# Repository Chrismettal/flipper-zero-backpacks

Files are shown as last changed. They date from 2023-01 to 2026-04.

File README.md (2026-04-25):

# Flipper Zero Backpacks <!-- omit in toc -->





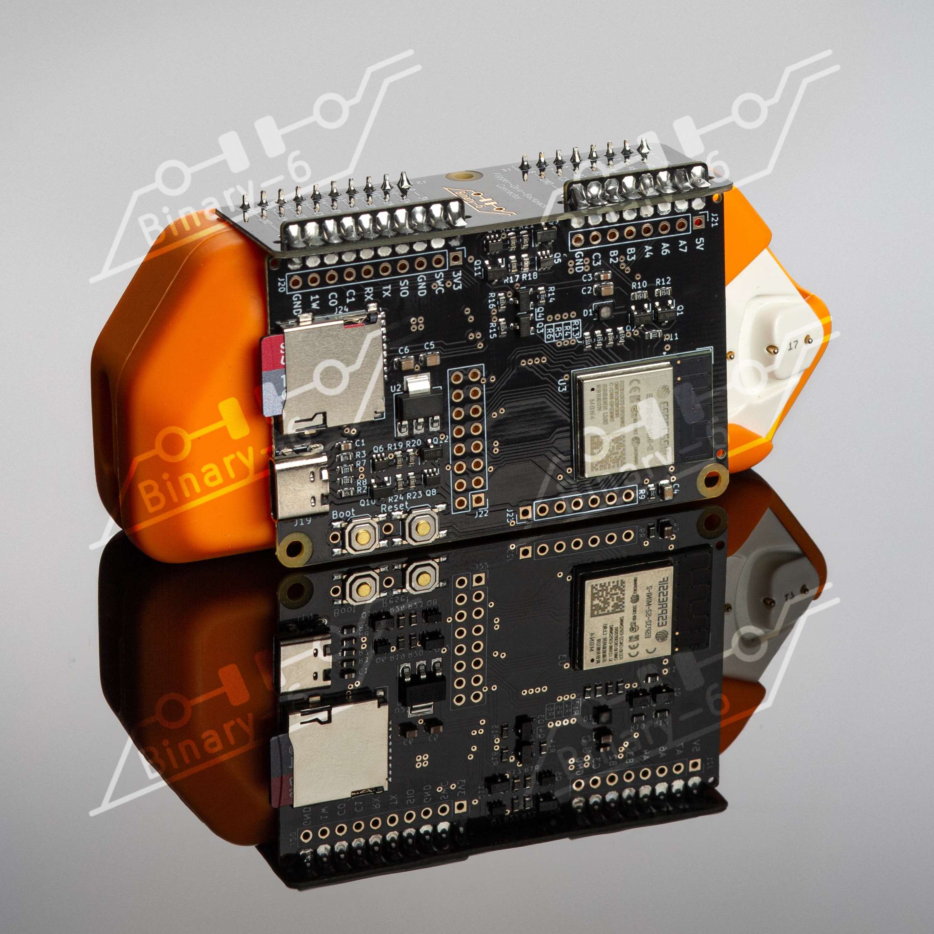
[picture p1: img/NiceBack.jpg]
NiceBack


This is a collection of addon boards for the [Flipper Zero](https://flipperzero.one/) multi-tool in the style of a backpack that clips behind the Flipper!

Right now it features only an ESP32 wifi board, like the official wifi devboard, only formatted as a backpack and with an SD card slot fitted. There is also a protoboard to create your own designs in the same formfactor.

The backpack framework is designed to fit snugly to a Flipper inside its silicone case. Without a silicone sleeve, the board will have 2mm of space around the Flipper, which might be undesireable.

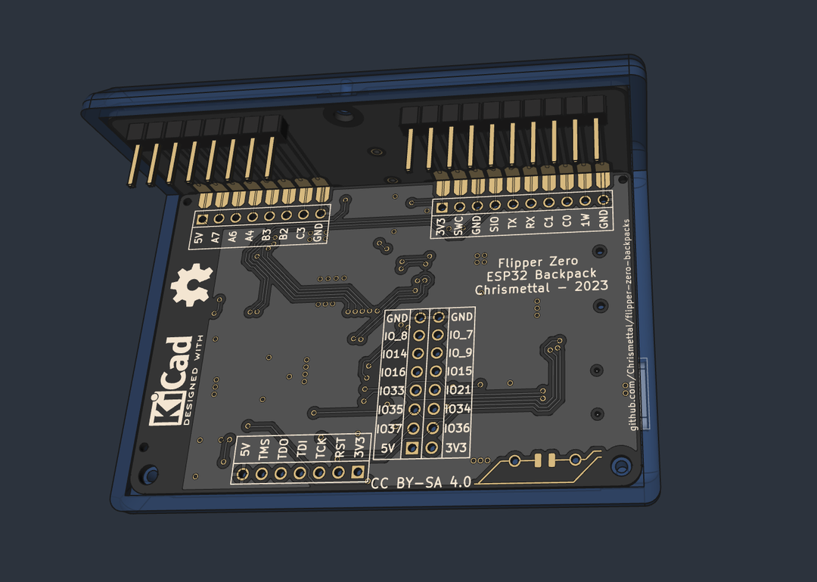
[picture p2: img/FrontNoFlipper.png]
FrontNoFlipper


Finished boards are currently stocked at [Elecrow](https://www.elecrow.com/store/Binary-6).

ElecrowBadge (https://www.elecrow.com/store/Binary-6)

**If you like my work please consider [supporting my caffeine addiction](https://github.com/Chrismettal#donations)!**

## Table of contents <!-- omit in toc -->

- [Boards](#boards)
  - [Connecting piece](#connecting-piece)
  - [ESP32 Wifi Dev board](#esp32-wifi-dev-board)
    - [Firmware](#firmware)
    - [Internal/External antenna](#internalexternal-antenna)
    - [SD Card](#sd-card)
  - [Protoboard](#protoboard)
  - [Raspberry Pi Zero W](#raspberry-pi-zero-w)
  - [Taylor Stahl - Mayhem](#taylor-stahl---mayhem)
- [Making your own](#making-your-own)
- [3D Printing](#3d-printing)
- [Building guide](#building-guide)
- [Sources](#sources)
- [Donations](#donations)
- [License](#license)

## Boards

All boards use `1mm board thickness` unless otherwise specified.

### Connecting piece

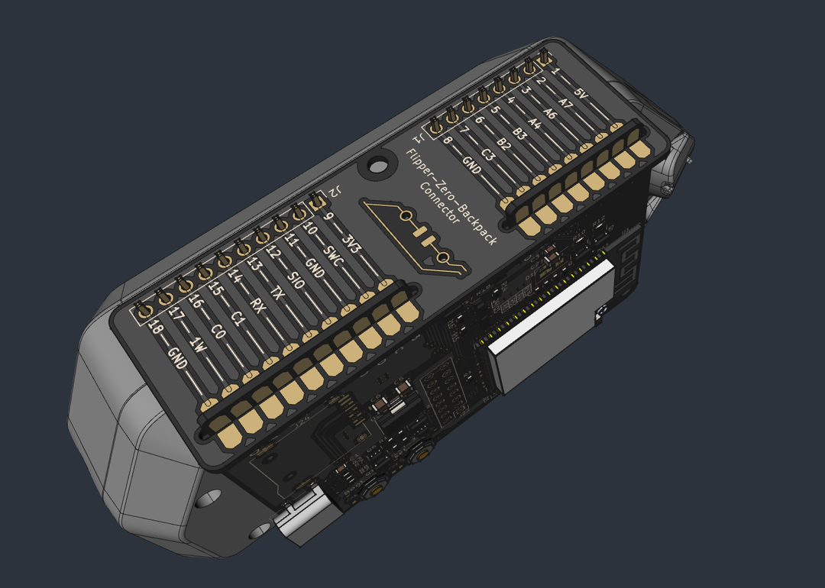
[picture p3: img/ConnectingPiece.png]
ConnectingPiece


Every board uses the same connector up top. This is what plugs into the Flipper and makes the board an actual backpack.
The addon board and the connecting piece slide into each other and get soldered at the intersection to form a solid, right angle connection.

### ESP32 Wifi Dev board

Wifi

[**Buy on Elecrow**](https://www.elecrow.com/flipper-zero-wifi-backpack-esp32-s2-mini-new-ic.html)

Very similar to the [official Wifi dev board](https://shop.flipperzero.one/collections/flipper-zero-accessories/products/wifi-devboard). Additionally includes a micro SD card slot so you don't have to mod the official board yourself. 

The board has been modified to accomodate the `ESP32-S2-MINI-2` version of the ESP32 modules, as the original `WROVER` variant has become unavailable. Internally the IC is mostly identical.

Other than that all guides applicable to the official Wifi dev board are also applicable here.

In this repo, there are 3D files for boards with the internal, as well as the external antenna available. The board is the same between the two, only the part number of the ESP changes.

#### Firmware

The board ships with the [Black Magic debugger firmware](https://black-magic.org/), just like the official board. Alternatively you can use an alternate firmware like the [ESP32 Marauder](https://github.com/justcallmekoko/ESP32Marauder/wiki/flipper-zero) by [JustCallMeKoko](https://github.com/justcallmekoko) if you want to get spicy.

**Every firmware that works on the [official dev board](https://shop.flipperzero.one/collections/flipper-zero-accessories/products/wifi-devboard) should also work on this backpack**

#### Internal/External antenna

Previous versions of this board used the `WROVER` variant of the ESP32, which offered internal and external antenna options on the same module by flipping a jumper. As this chip has become unavailable, the board has been redesigned for the `ESP32-S2-MINI-2`, which at first is internal-antenna-only. To use an external antenna, the `ESP32-S2-MINI-2` would need to be mounted. 

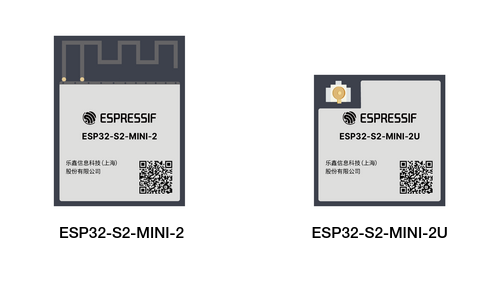
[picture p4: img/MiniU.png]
ESP32 MINI vs MINI U


#### SD Card

The ESP seems to be pretty restrictive in SD Card compatibility especially when running Marauder. This is not a limitation of this specific design but inherent to the ESP32. I've had luck with older and smaller SD cards sub 16 GB and Class 10 at max. OLDER `Sandisk Ultra Micro SDHC I` seem to work pretty well when formatted to `FAT32`.

### Protoboard

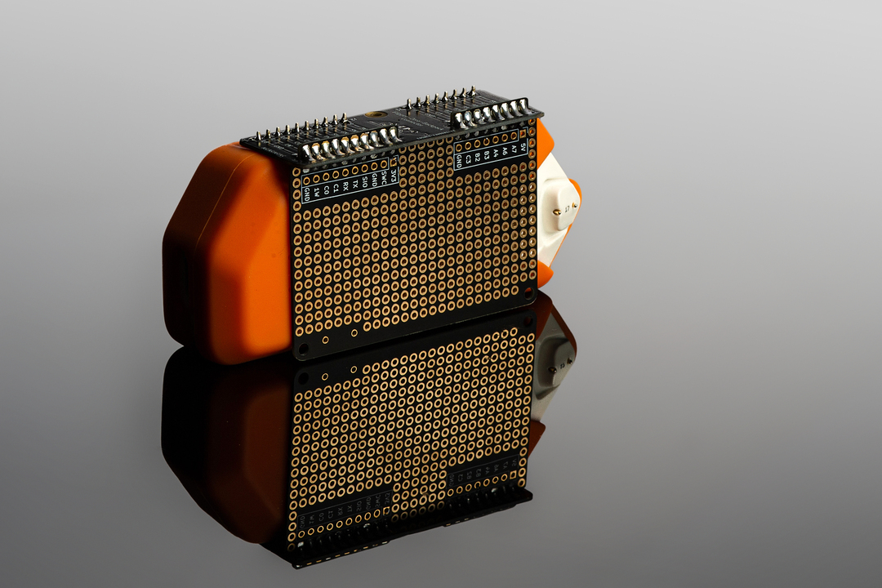
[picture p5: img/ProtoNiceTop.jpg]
Protoboard


A simple `2.54mm` pitch protoboard backpack, fitting the same case as the ESP32 board. While it is through hole, beware that there isn't much space between the Flippers silicone case and the board, so make sure to only put taller components on the side facing away from the flipper, and stay pretty flat when wiring on the bottom side. Also remember that the bottom side will be somewhat exposed, so you should consider placing and wiring mostly on the encased side.

### Raspberry Pi Zero W

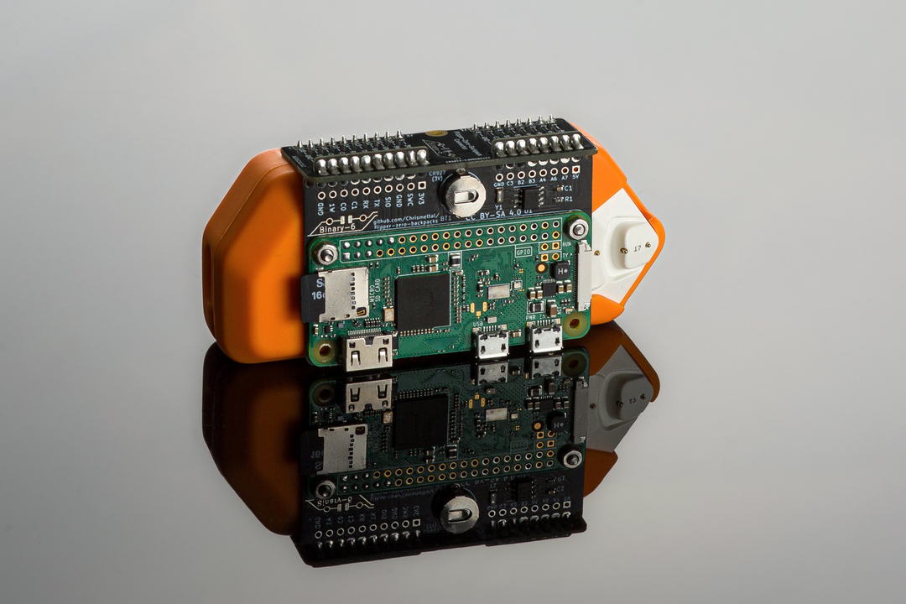
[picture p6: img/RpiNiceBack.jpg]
Raspberry


This is an adapter to supply and connect a Raspberry Pi Zero W to the Flipper via UART.

The board was mainly created for the [Flippagotchi](https://github.com/Matt-London/pwnagotchi-flipper) app, which renders a [Pwnagotchi](https://pwnagotchi.ai/)`s screen onto the flipper.

Additionally, the board includes a `PCF8523` realtime clock so your Pwnagotchi actually knows what time it is. The battery used for the RTC is a `CR927`.

To set up the Realtime clock, you can follow the guide on the [Pwnagotchi docs](https://pwnagotchi.ai/configuration/#connecting-to-pi0w-with-microusb-cable-on-linux-host) as well as [Adafruit](https://learn.adafruit.com/adding-a-real-time-clock-to-raspberry-pi/set-rtc-time).

If you don't want to connect your pwnagotchi to the internet, you can always set its time with `'sudo date -s 'YYYY-MM-DD HH:MM:SS'` , before writing the Raspberry's time the RTC with `sudo hwclock -w`

### Taylor Stahl - Mayhem

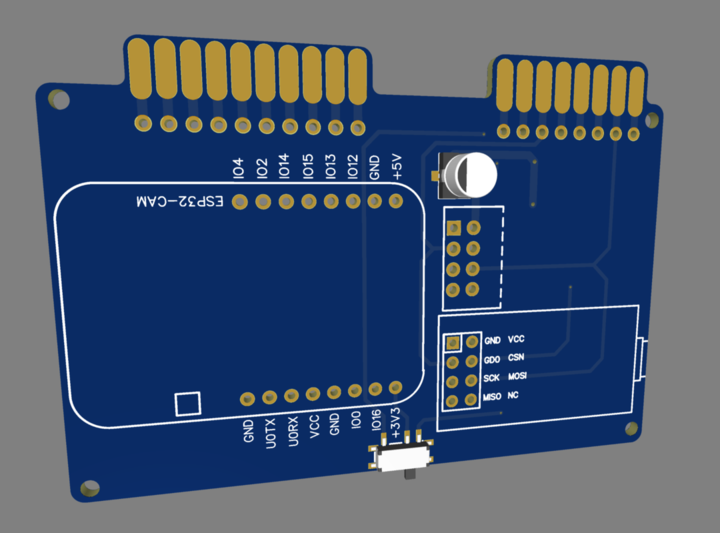
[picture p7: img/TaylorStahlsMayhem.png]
Mayhem


This is a [Flipper Zero Mayhem](https://github.com/eried/flipperzero-mayhem) backpack created by [Taylor Stahls](taylor.stahls@gmail.com) done with EasyEDA.

It uses the same backpack connector as the other boards found here to implement an ESP32-CAM, CC1101 and NRF24 in a backpack format. A switch was added to choose between the CC1101 and the NRF24 being active.

I personally haven't yet played around with this board, as Taylor merely asked me to add his board to this repo to respect the original license. Taylor is currently setting up his own Tindie shop to sell his Mayhem boards eventually. Link to be added once public.

## Making your own

All files to order your own boards from existing designs can be found under `/pcb/<BoardName>/FabricationFiles`. This includes Gerbers as well as BOMs for PCBA so the boards arrive fully built. All files were exported to be ordered at JLCPCB and use LCSC part numbers.

**All boards need to be ordered as 1mm thickness so they fit together well!**

There is also a clean KiCad project under `/pcb/Clean/` to create original designs. If you end up creating your own design I would love to merge your fork into this repo!

## 3D Printing

A 3D printable case project is included in `/3d_printing/flipper-zero-backpacks.FCStd`.

You can use [FreeCAD](https://www.freecad.org/) to open and modify it. 

A `bare` version, as well as one fitting the `ESP32` board have been exported as `.step` and `.3mf` files into `/3d_printing/`.

The cases can be printed without any supports and are best printed in PETG, but there is no reason why PLA wouldn't be sufficient.

## Building guide

Please head over to [the building guide document](/Guide/README.md)!

## Sources

- [ESP32-S2-WROVER step file](https://grabcad.com/library/esp32-s2-wrover-1)

## Donations

**If you like my work please consider [supporting my caffeine addiction](https://github.com/Chrismettal#donations)!**

## License

 <br />This work is licensed under a <a rel="license" href="http://creativecommons.org/licenses/by-sa/4.0/">Creative Commons Attribution-ShareAlike 4.0 International License</a>.

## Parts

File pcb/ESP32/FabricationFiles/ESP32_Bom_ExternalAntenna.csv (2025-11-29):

Comment | Designator | Footprint | LCSC
100nF | C1,C3 | Capacitor_SMD:C_0603_1608Metric | C14663
22uF | C2,C6 | Capacitor_SMD:C_0805_2012Metric | C45783
10uF | C4,C5 | Capacitor_SMD:C_0805_2012Metric | C15850
LED_RBAG | D1 | MeineBib:LED_RGB_2.1mm_Foshan_Nationstar | C2874116
XUNPU TYPEC-304-ACP16 | J19 | MeineBib:USB_C_Receptacle_XUNPU_TYPEC-304-ACP16 | C2982555
Micro_SD_XUNPU__TF-115 | J24 | MeineBib:Micro_SD_XUNPU_TF-115 | C266620
AO3400A | Q1,Q2 | Package_TO_SOT_SMD:SOT-23 | C20917
AO3401A | Q3,Q4,Q9,Q10,Q11,Q12 | Package_TO_SOT_SMD:SOT-23 | C15127
MMDT2907A-7-F | Q5,Q6,Q7,Q8 | Package_TO_SOT_SMD:SOT-363_SC-70-6 | C460232
4K7 | R15,R16 | Resistor_SMD:R_0603_1608Metric | C23162
100k | R17,R18,R19,R20,R21,R22,R23,R24 | Resistor_SMD:R_0603_1608Metric | C25803
5.1K | R2,R3 | Resistor_SMD:R_0603_1608Metric | C23186
100R | R4 | Resistor_SMD:R_0603_1608Metric | C22775
150R | R5,R10,R12,R13 | Resistor_SMD:R_0603_1608Metric | C22808
510R | R6 | Resistor_SMD:R_0603_1608Metric | C23193
22R | R7,R8 | Resistor_SMD:R_0603_1608Metric | C23345
10k | R9,R11,R14 | Resistor_SMD:R_0603_1608Metric | C25804
Reset | SW1 | Button_Switch_SMD:SW_SPST_TL3342 | C318884
Boot | SW2 | Button_Switch_SMD:SW_SPST_TL3342 | C318884
ESP32-S2-MINI-2U | U3 | RF_Module:ESP32-S2-MINI-2U | C3013907
AMS1117-3.3 | U2 | Package_TO_SOT_SMD:SOT-223-3_TabPin2 | C6186

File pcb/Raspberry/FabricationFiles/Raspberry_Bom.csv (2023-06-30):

Comment | Designator | Footprint | LCSC
CR927 (3V) | BT1 | MeineBib:MY-927-01 CR927 Battery Holder | C964850
2.2µF | C1 | Capacitor_SMD:C_0603_1608Metric | C23630
1K | R1 | Resistor_SMD:R_0603_1608Metric | C21190
PCF8523T | U1 | Package_SO:SOIC-8_3.9x4.9mm_P1.27mm | C2651516
32.768kHz | Y1 | Crystal:Crystal_SMD_3215-2Pin_3.2x1.5mm | C32346

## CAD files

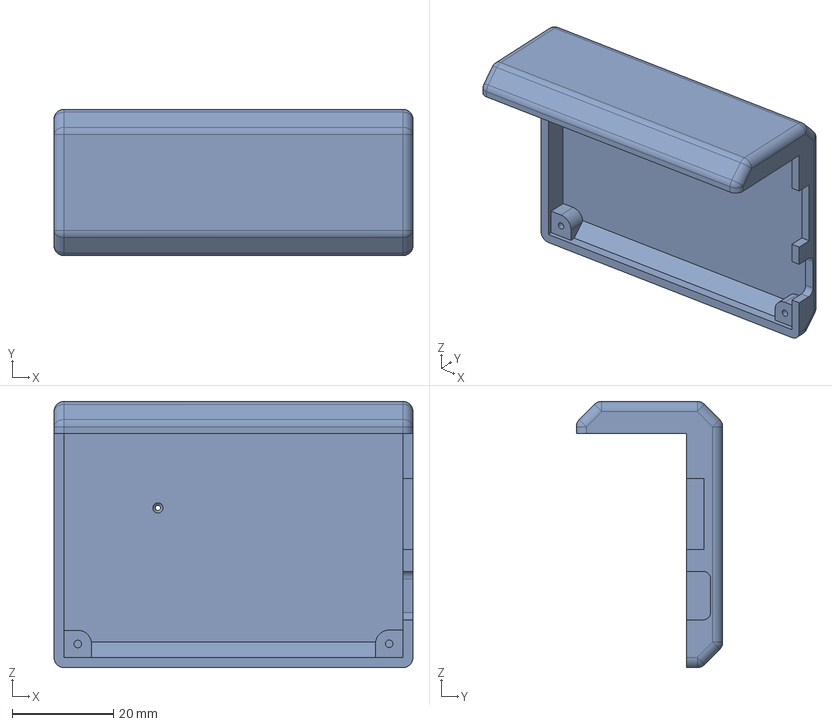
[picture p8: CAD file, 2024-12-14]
3d_printing/ESP32_InternalAntenna.step
70.8 x 28.9 x 52.5 mm

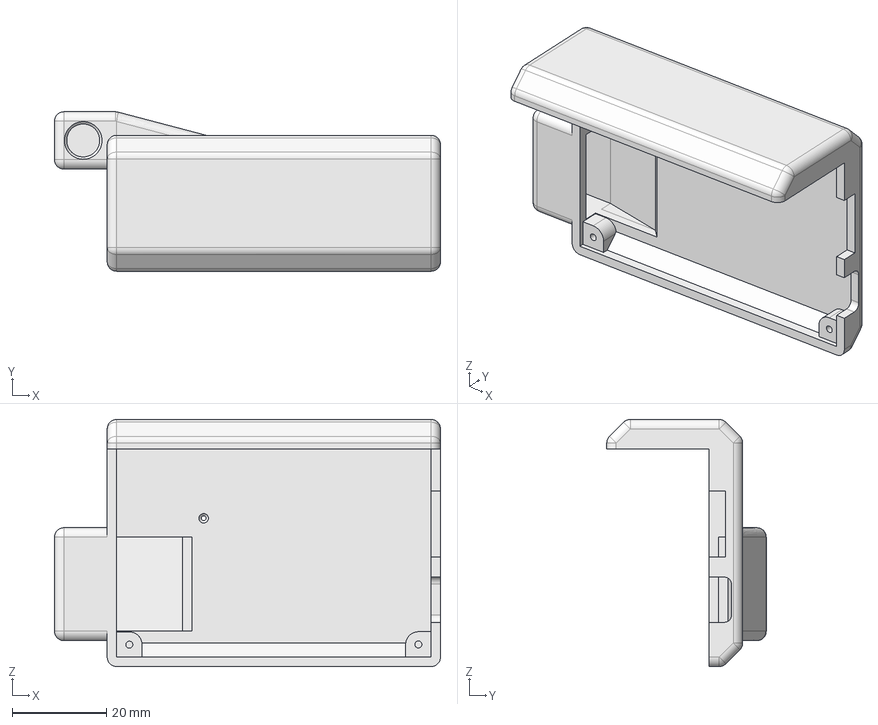
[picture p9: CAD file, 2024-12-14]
3d_printing/ESP32_ExternalAntenna.step
82.0 x 33.9 x 52.5 mm

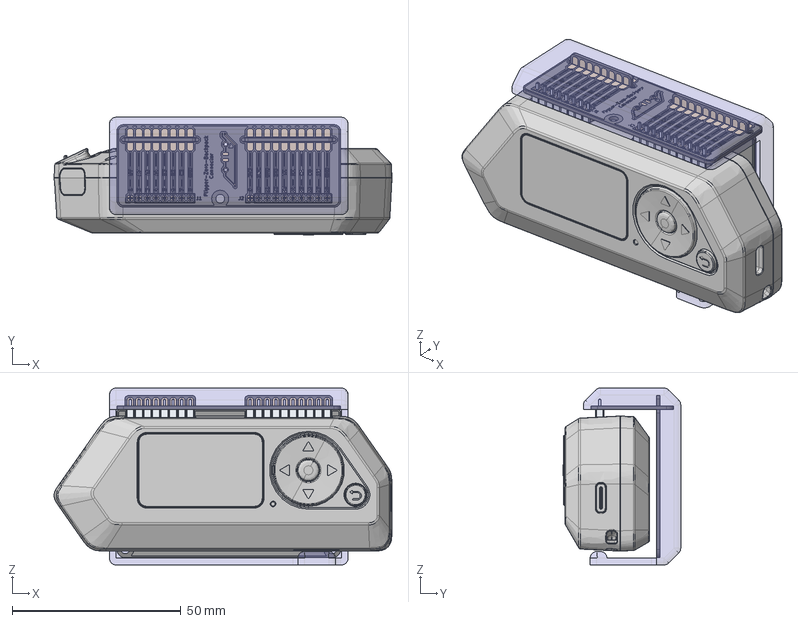
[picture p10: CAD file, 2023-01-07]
3d_printing/flipper-zero-backpacks.FCStd
100.3 x 34.9 x 52.5 mm
flipper-zero-body-3d
J2_PinHeader_1x10_P254mm_Vertical_2ab44282e7fd
J1_PinHeader_1x08_P254mm_Vertical_c51476792754
Pcb_2d78
topPads_2d78
topTracks_2d78
topZones_2d78
botPads_2d78
botTracks_2d78
botZones_2d78
topSilks_7e
Pcb_c4c1
topPads_c4c1
topZones_c4c1
botPads_c4c1
botZones_c4c1
Case

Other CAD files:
3d_printing/Bare.step
3d_printing/Raspberry.step
3d_printing/Bare.3mf
3d_printing/ESP32_ExternalAntenna.3mf
3d_printing/ESP32_InternalAntenna.3mf
3d_printing/Raspberry.3mf

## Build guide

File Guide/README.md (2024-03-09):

# Building guide <!-- omit in toc -->

- [BOM](#bom)
    - [Bare / Prototype](#bare--prototype)
    - [ESP32 Internal Antenna](#esp32-internal-antenna)
    - [ESP32 External Antenna](#esp32-external-antenna)
    - [Raspberry Pi](#raspberry-pi)
- [3D printing](#3d-printing)
- [Assembling the boards](#assembling-the-boards)
- [Raspberry Pi specific subassembly](#raspberry-pi-specific-subassembly)
- [Firmware flash](#firmware-flash)
    - [ESP32](#esp32)

## BOM

These BOMs are for assembling a finished backpack and are to be seen additional to the PCBA BOMs in the respective pcb folder. These BOMs will not include any parts that are placed on the board by the PCB fabhouse.

This list is also what you would get, if you were to buy a kit through [Tindie](https://www.tindie.com/stores/binary-6/).

### Bare / Prototype

| Name | Part number  | Amount | Link |
| :--- | :--- | :----- | :--- |
| Protoboard PCB | N/A | 1 | [PCB](/pcb/Protoboard/FabricationFiles/Protoboard_Gerb.zip) |
| Connecting-piece PCB | N/A | 1 | [PCB](/pcb/Connecting-piece/FabricationOutputs/Connecting-piece_Gerb.zip) |
| 8 x 2.54mm pin header | N/A | 1 | N/A |
| 10 x 2.54mm pin header | N/A | 1 | N/A |
| 3D printed case | N/A | 1 | [Case](/3d_printing/Bare.3mf) |
| M2 x 5mm self tapping screw | GB2670.2 5mm | 3 | [M2 x 5 noname screws](https://de.aliexpress.com/item/1005004325435136.html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) |

### ESP32 Internal Antenna

| Name | Part number  | Amount | Link |
| :--- | :--- | :----- | :--- |
| ESP32 PCB (With `ESP32-S2-WROVER`, `C701333`) | N/A | 1 | [PCB](/pcb/ESP32/FabricationFiles/ESP32_Gerb.zip), [PCBA BOM](/pcb/ESP32/FabricationFiles/ESP32_Bom_InternalAntenna.csv) |
| Connecting-piece PCB | N/A | 1 | [PCB](/pcb/Connecting-piece/FabricationOutputs/Connecting-piece_Gerb.zip) |
| 8 x 2.54mm pin header | N/A | 1 | N/A |
| 10 x 2.54mm pin header | N/A | 1 | N/A |
| 3D printed case | N/A | 1 | [Case](/3d_printing/ESP32_InternalAntenna.3mf) |
| M2 x 5mm self tapping screw | GB2670.2 5mm | 3 | [M2 x 5 noname screws](https://de.aliexpress.com/item/1005004325435136.html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) |

### ESP32 External Antenna

| Name | Part number  | Amount | Link |
| :--- | :--- | :----- | :--- |
| ESP32 PCB (With `ESP32-S2-WROVER-I`, `C701334`) | N/A | 1 | [PCB](/pcb/ESP32/FabricationFiles/ESP32_Gerb.zip), [PCBA BOM](/pcb/ESP32/FabricationFiles/ESP32_Bom_InternalAntenna.csv) |
| Connecting-piece PCB | N/A | 1 | [PCB](/pcb/Connecting-piece/FabricationOutputs/Connecting-piece_Gerb.zip) |
| 8 x 2.54mm pin header | N/A | 1 | N/A |
| 10 x 2.54mm pin header | N/A | 1 | N/A |
| 3D printed case | N/A | 1 | [Case](/3d_printing/ESP32_InternalAntenna.3mf) |
| M2 x 5mm self tapping screw | GB2670.2 5mm | 3 | [M2 x 5 noname screws](https://de.aliexpress.com/item/1005004325435136.html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) |
| 2.4GHz Wifi Antenna with IPX to RP-SMA cable | N/A | 1 | [Noname Antenna](https://de.aliexpress.com/item/1005003489327360.html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) |

### Raspberry Pi

| Name | Part number | Amount | Link |
| :--- | :--- | :----- | :--- |
| Raspberry PCB | N/A | 1 | [PCB](/pcb/Raspberry/FabricationFiles/Raspberry_Gerb.zip), [PCBA BOM](/pcb/Raspberry/FabricationFiles/Raspberry_Bom.csv) |
| Connecting-piece PCB | N/A | 1 | [PCB](/pcb/Connecting-piece/FabricationOutputs/Connecting-piece_Gerb.zip) |
| 8 x 2.54mm pin header | N/A | 1 | N/A |
| 10 x 2.54mm pin header | N/A | 1 | N/A |
| Raspberry Pi Zero W | RPD08818W | 1 | [Elecrow Rpi Zero W](https://www.elecrow.com/raspberry-pi-zero-w.html) |
| 3D printed case | N/A | 1 | [Case](/3d_printing/ESP32_InternalAntenna.3mf) |
| M2 x 5mm self tapping screw | GB2670.2 5mm | 3 | [M2 x 5 noname screws](https://de.aliexpress.com/item/1005004325435136.html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) |
| M2.5 Hexagon Nut | DIN-EN-ISO 4032 | 2 | [Norm](https://www.fasteners.eu/standards/ISO/4032/) |
| M2.5 x 6mm countersunk machine screw | ISO 14581 | 2 | [Norm](https://www.fasteners.eu/standards/ISO/14581/) |
| CR927 (3V) Battery | N/A | 1 | N/A |

## 3D printing

In the [3d_printing](/3d_printing/) folder you'll find a case option for every design variant. The cases are to be printed with PETG with 0.15mm layer height and a 0.4mm nozzle. Larger layer heights or nozzles might make the boards not fit easily.

The cases currently provided are:

- Bare (Case without cutouts for prototyping)
- ESP32_InternalAntenna (Wifi dev board using the on-board ESP32 antenna. Sleek and compact)
- ESP32_ExternalAntenna (Wifi dev board using an external antenna. Powerful but bulky)
- Raspberry (Pi Zero mount)

## Assembling the boards

**Step 1 - Clamp the back board vertically**

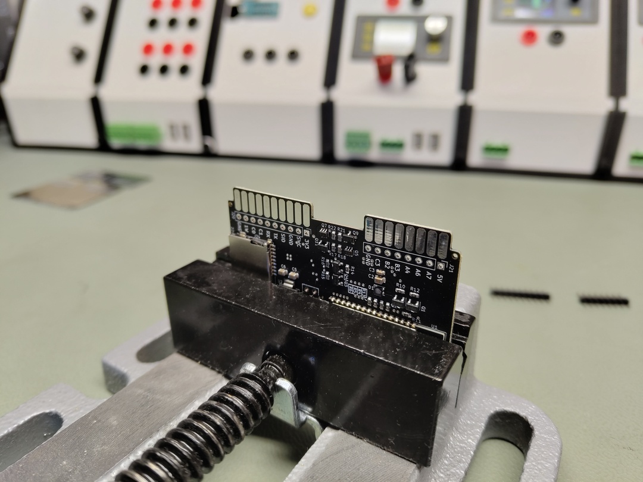
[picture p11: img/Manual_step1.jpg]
Step1


**Step 2 - Slide on the connecting piece**

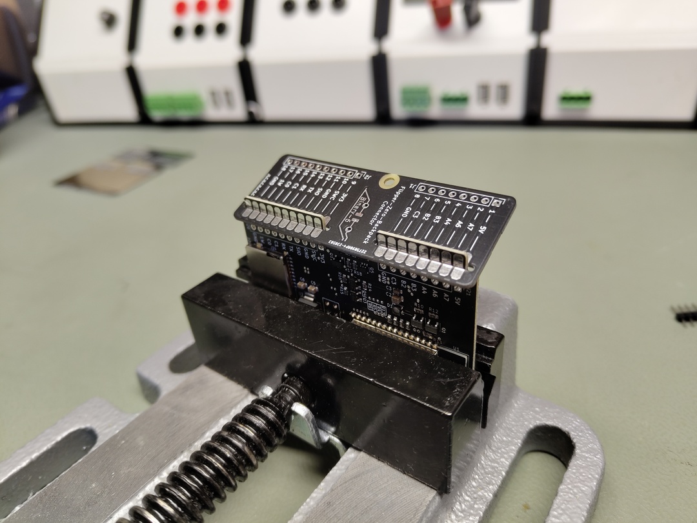
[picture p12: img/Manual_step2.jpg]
Step2


**Step 3 - Solder down one of the connectors**

You don't have to care about the angle of the boards for now.

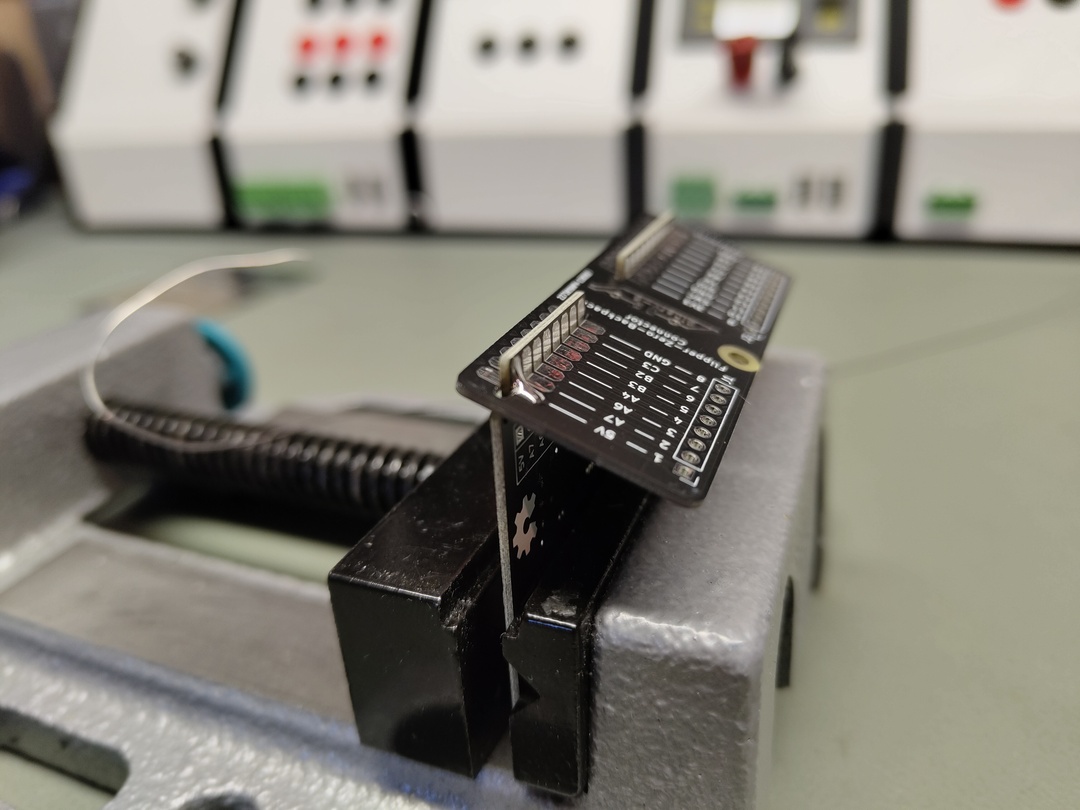
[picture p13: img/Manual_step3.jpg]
Step3


**Step 4 - Reflow the connection, aligning the boards at 90 degrees**

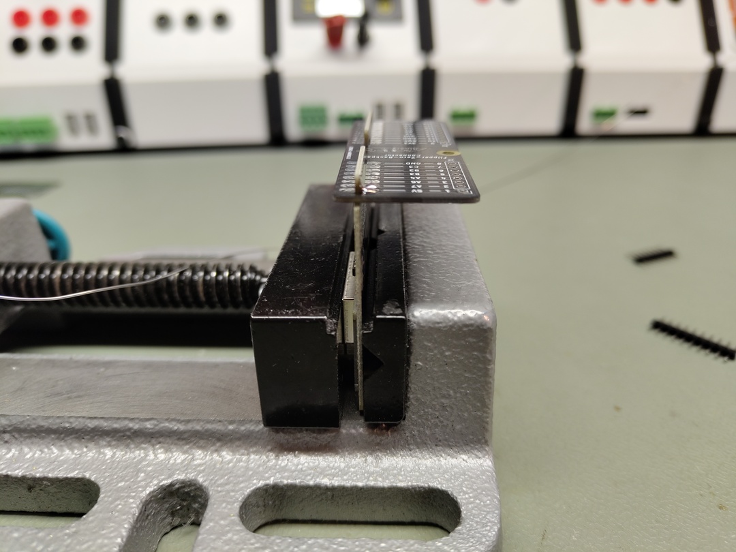
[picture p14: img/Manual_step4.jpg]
Step


**Step 5 - Make sure the boards are also aligned when viewed from the front**

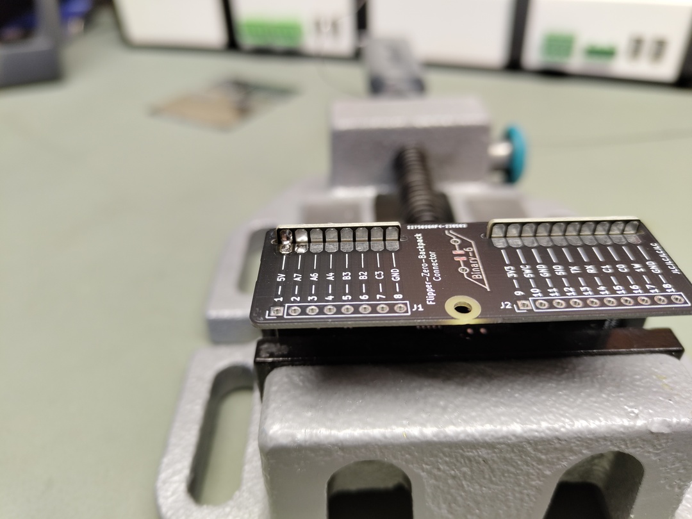
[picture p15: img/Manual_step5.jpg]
Step5


**Step 6 - Solder the remaining connections on the top**

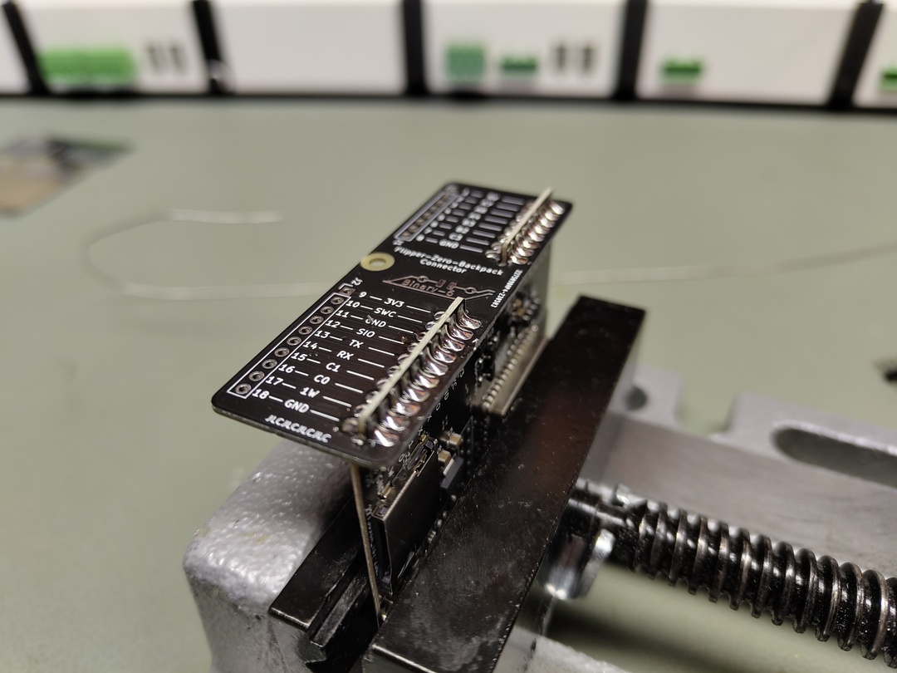
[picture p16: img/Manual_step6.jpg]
Step6


**Step 7 - Make sure that none of the connections are bridged between the pads horizontally**

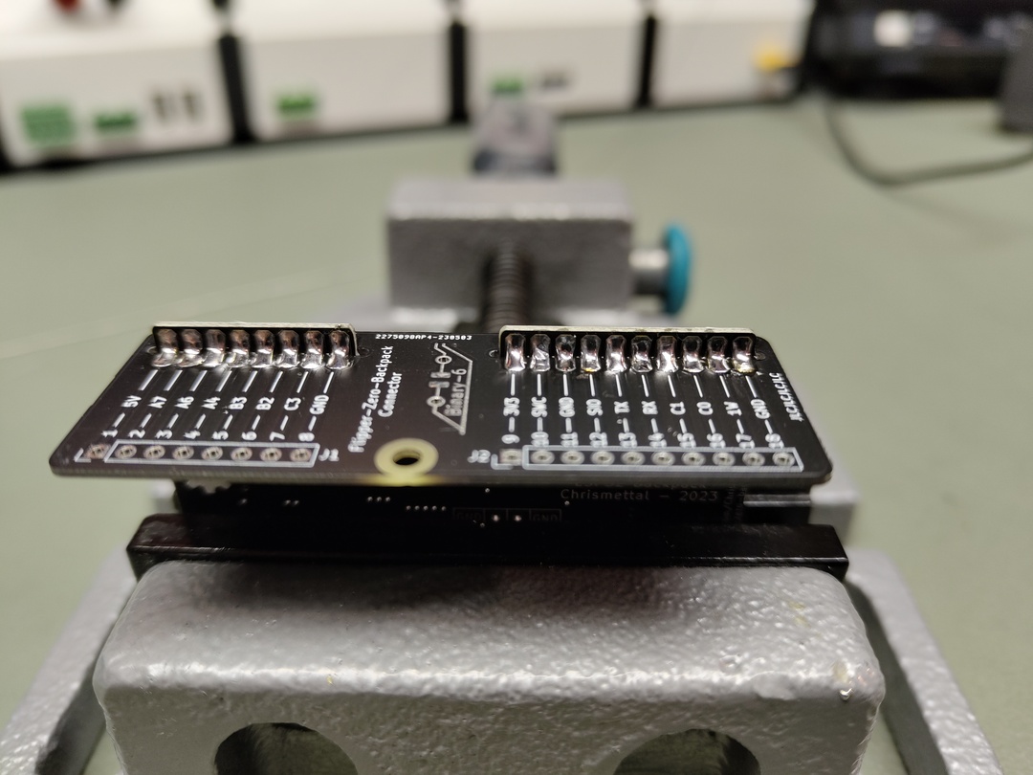
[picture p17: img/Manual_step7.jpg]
Step7


**Step 8 - Flip the board around so you can see the bottom connections**

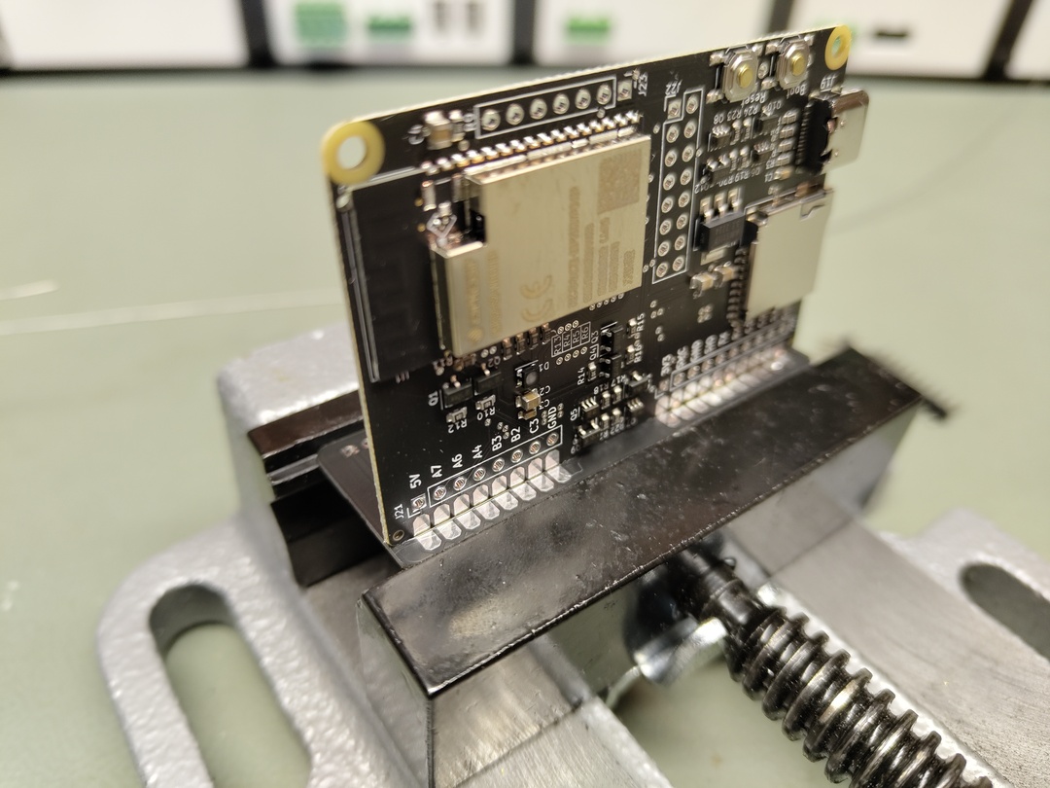
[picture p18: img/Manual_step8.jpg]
Step8


**Step 9 - Solder the bottom connections**

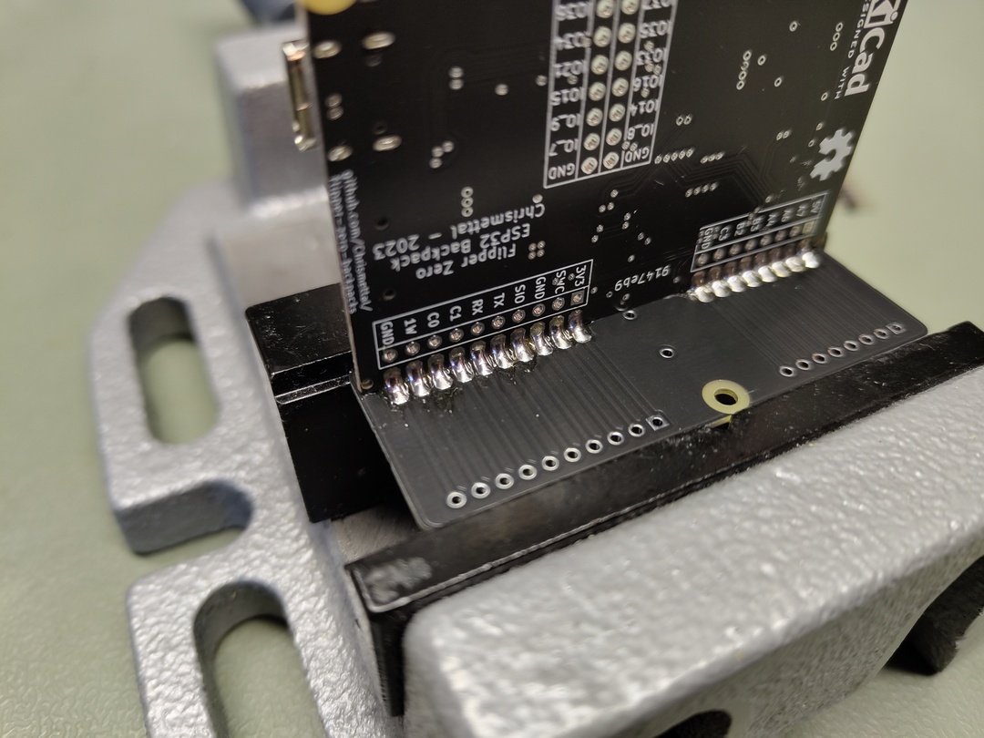
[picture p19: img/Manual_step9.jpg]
Step9


**Step 10 - Flip the board around again and solder the pin headers**

Make sure to get them at a right angle to the board as well. Otherwise you will put stress on the board when inserting into the Flipper.

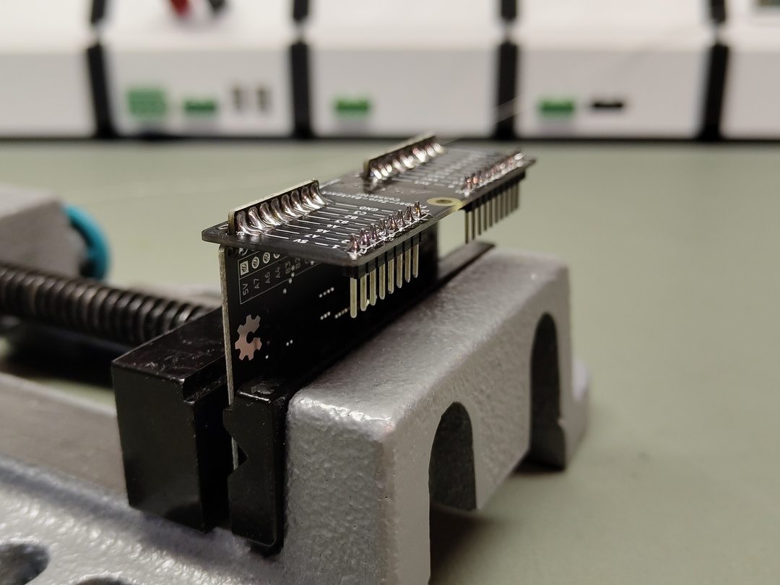
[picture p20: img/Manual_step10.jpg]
Step10


**Step 11 - Optional - Find the 3D printed case and screws**

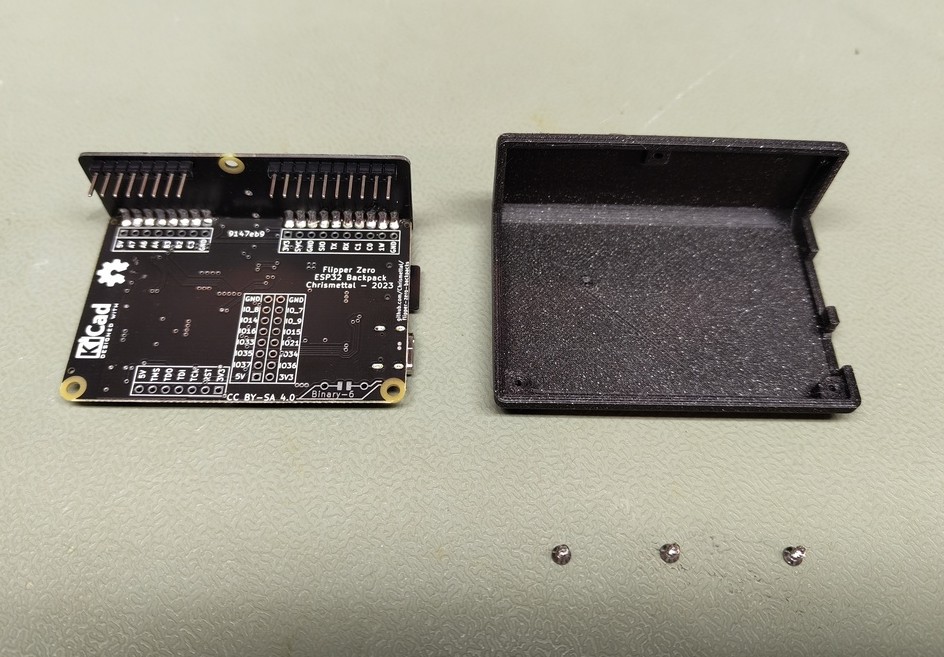
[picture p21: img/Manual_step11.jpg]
Step11


<details>
<summary markdown="span">Excursion: Installing the antenna jack for external antenna boards</summary>

**Step 11.1 - Insert the antenna jack into the slot and fix nut from the outside**

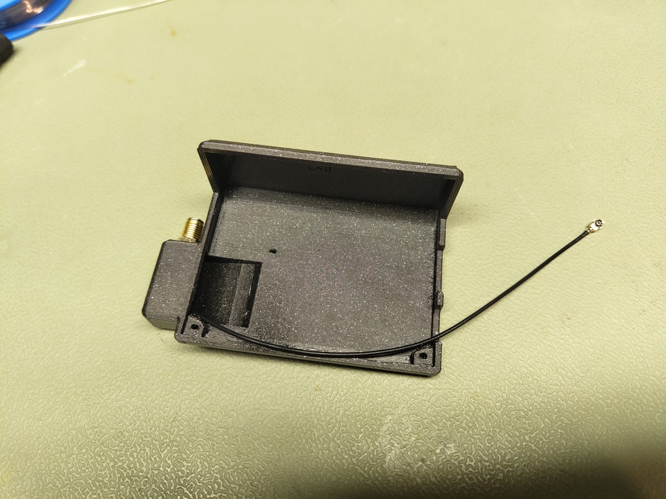
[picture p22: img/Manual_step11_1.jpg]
Step11.1


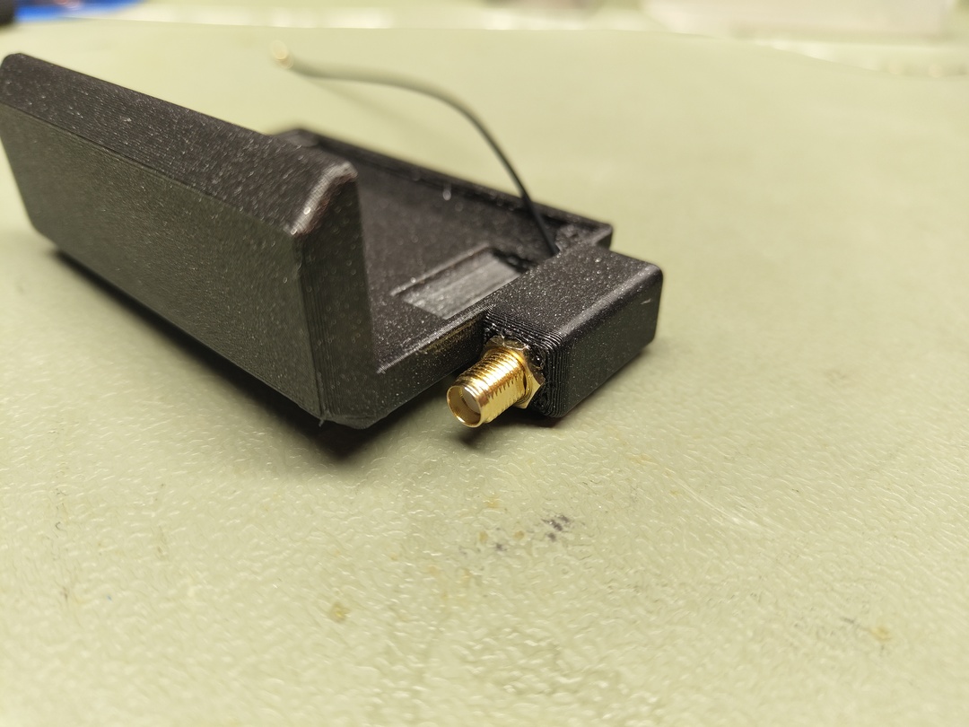
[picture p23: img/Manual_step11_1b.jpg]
Step11.1b


**Step 11.2 - Plug antenna extension into the board**

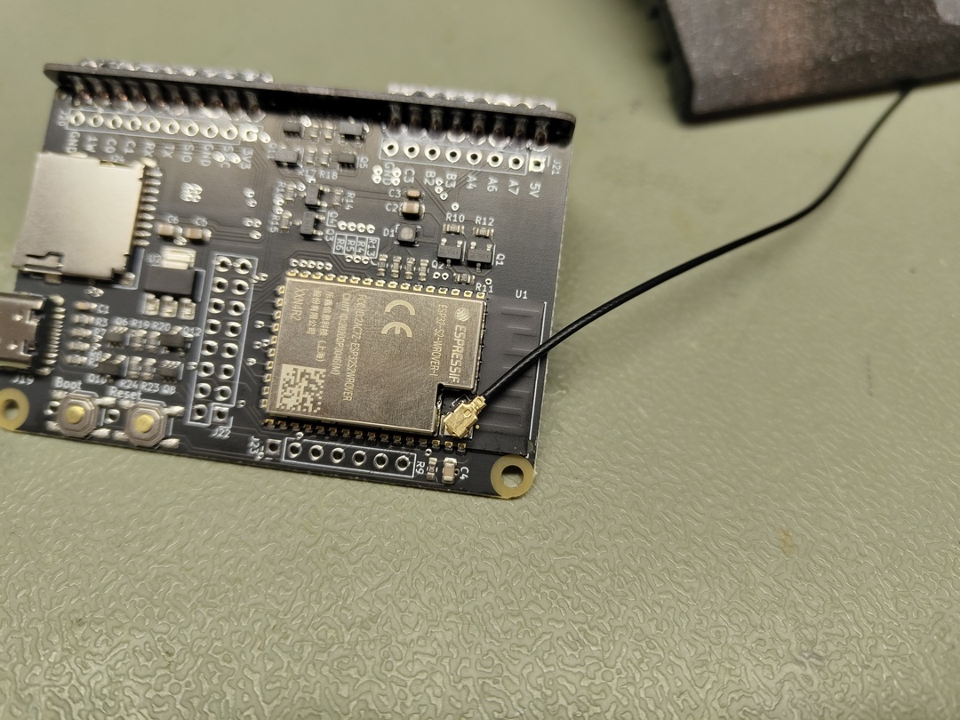
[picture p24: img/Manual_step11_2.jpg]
Step11.2


**Step 11.3 - Carefully route the extension while inserting the board**

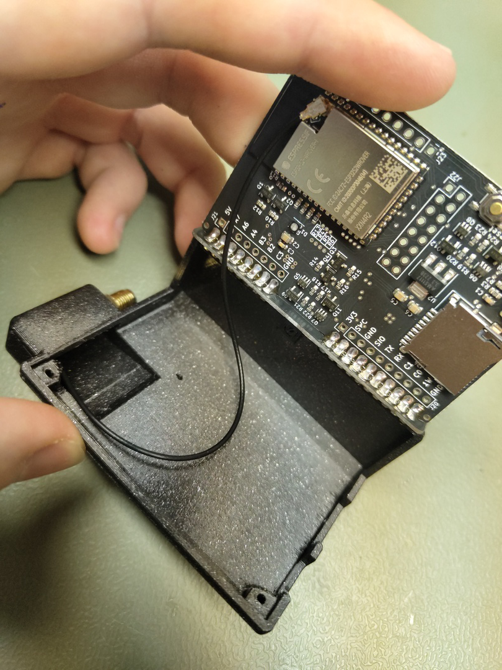
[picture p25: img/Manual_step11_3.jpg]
Step11.3


**Step 11.4 - Make sure the board is seated without pinching the wire**

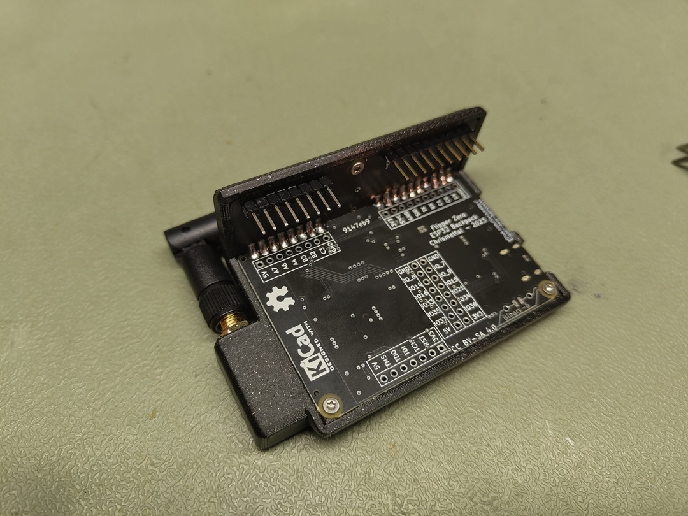
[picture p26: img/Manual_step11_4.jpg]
Step11.4


</details>

**Step 12 - Slide the board into the case and screw down the 3 mounting points**

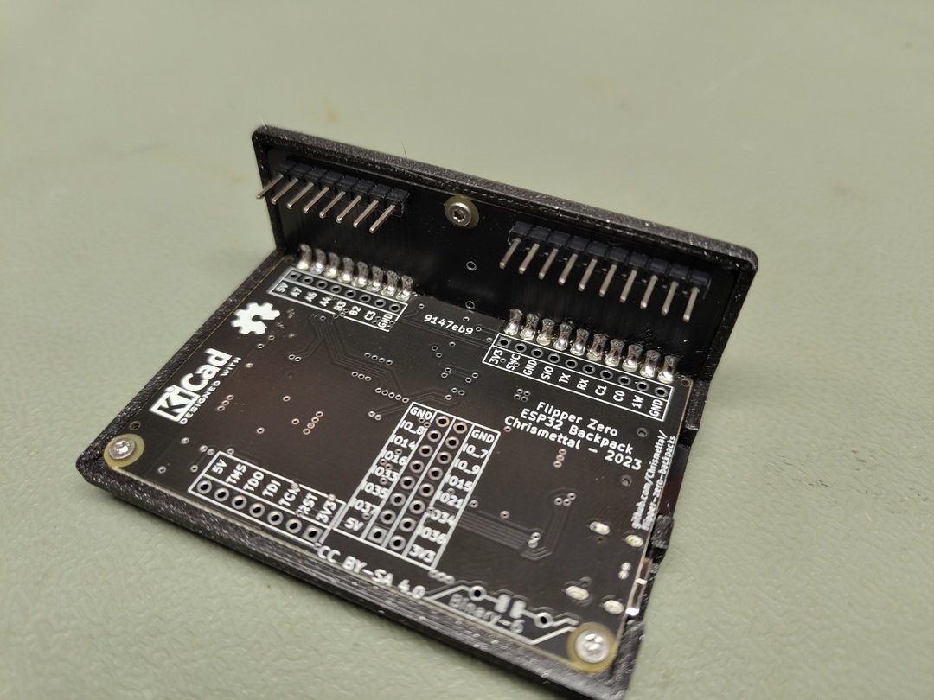
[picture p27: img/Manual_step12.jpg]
Step12


## Raspberry Pi specific subassembly

**Step 0 - Find the Raspberry board and read the instructions as printed on the board**

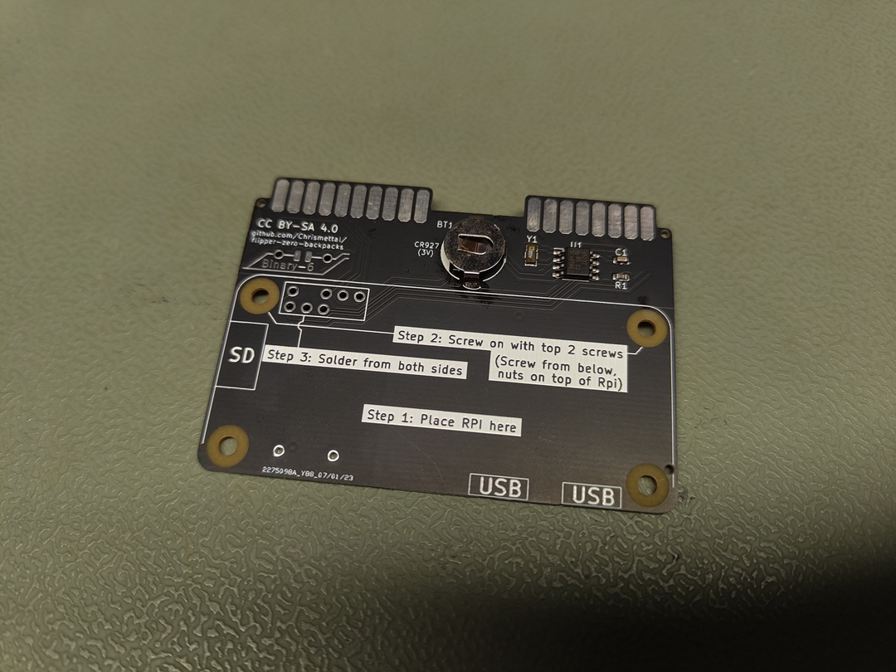
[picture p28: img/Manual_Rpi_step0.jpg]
Step0


**Step 1 - Place the Raspberry Pi Zero W on top of the board**

Note the lack of pin headers. The board won't fit with headers installed!

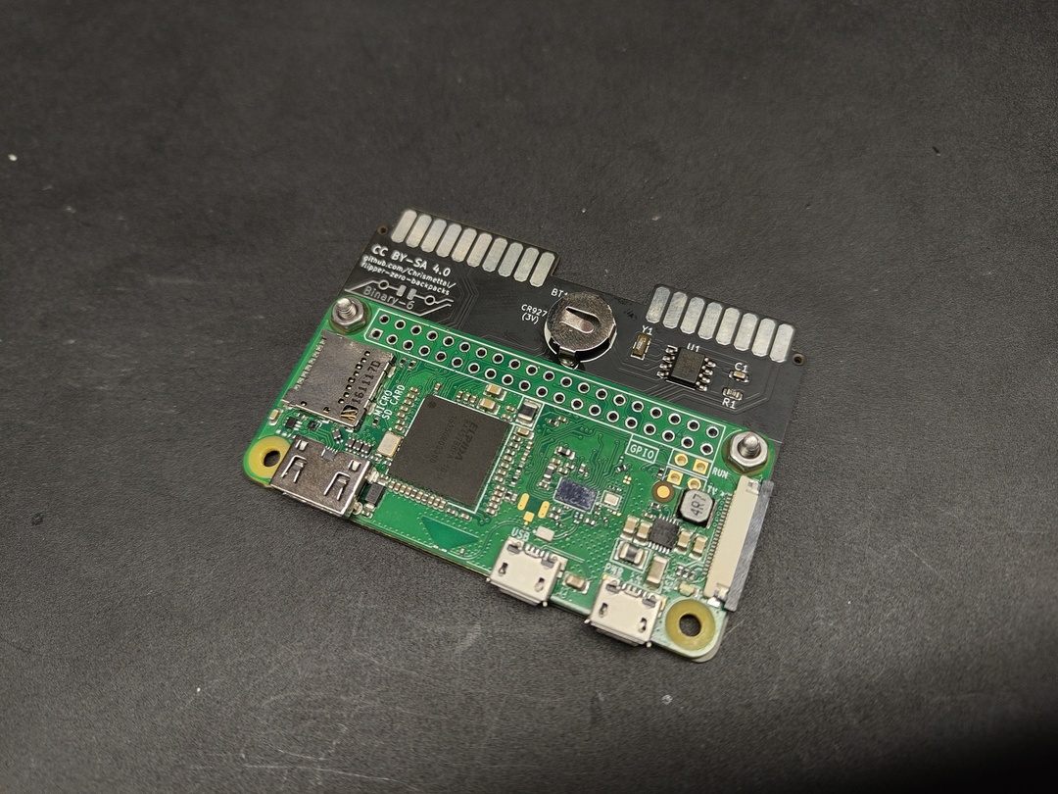
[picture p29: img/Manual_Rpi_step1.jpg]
Step1


**Step 2 - Screw down the Raspberry Pi Zero W using M2.5 screws and nuts from behind**

The screws are countersunk into the PCB so they will be flat from the outside

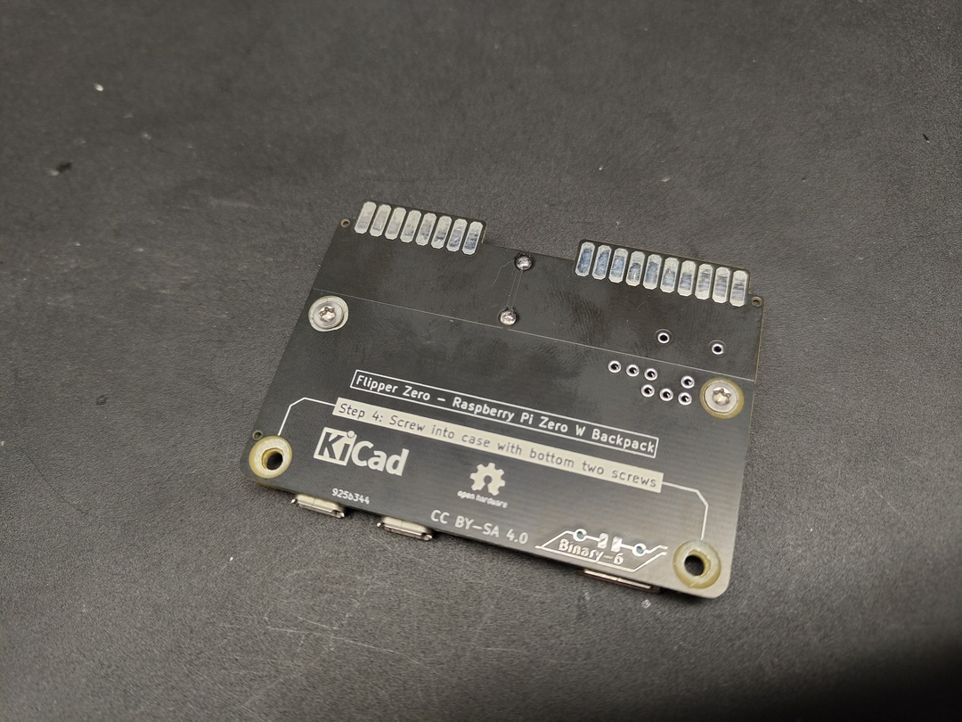
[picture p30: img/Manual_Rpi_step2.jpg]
Step2


**Step 3 - Solder the 7 connections through both boards**

With the Pi face down, heat the pads from the backpack board and apply solder into the hole. You will see the solder "bubble down" through both holes forming a connection between the boards.

Flipping the board to the front you should see solder ran all the way through both boards. This picture shows 50% of the solder process done, having soldered only from the back:

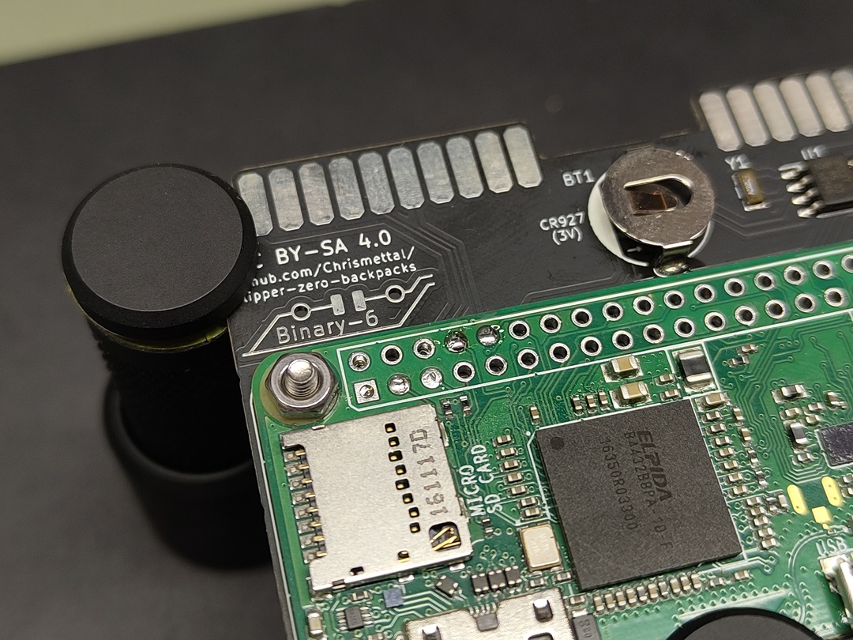
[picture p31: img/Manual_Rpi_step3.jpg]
Step3


When it looks like this, apply some solder from the top as well to make the connections look nice from both sides.

**Step 4 - The finished board should look like this**

You should now see clean connections between both sides of the board. You can now insert the CR927 battery for the RTC if desired, and continue with the rest of the general build guide, to assemble your backpack.

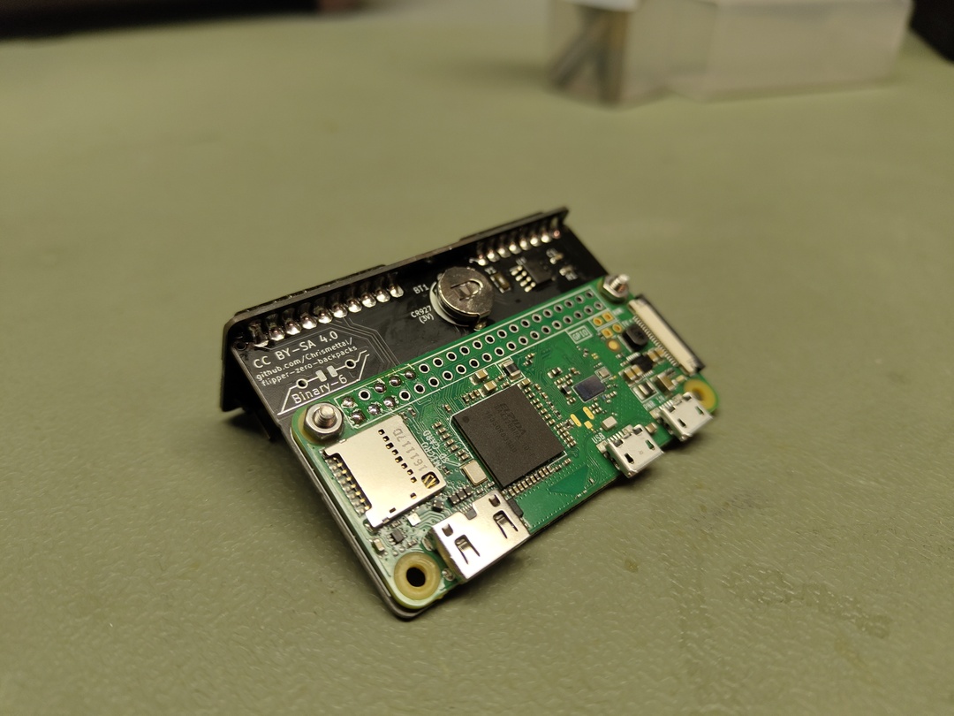
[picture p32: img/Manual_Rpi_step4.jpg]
Step4


## Firmware flash

### ESP32

I recommend using [FZEasyMarauderFlash](https://github.com/SkeletonMan03/FZEasyMarauderFlash) for this. It allows you to flash either the BlackMagic Firmware that Flipper itself ships with their Devboards, as well as Marauder or Evil Portal.

Instructions are done using a fresh Arch install.

1. Make sure you have git python and pip installed:

`sudo pacman -S --needed python python-pip git`

2. Add your current user to the `uucp` group (sometimes `dialout` on other OSes)

`sudo usermod -a -G uucp $USER`

3. Download appropriate UDEV rules (Grabbing from Platformio for convenience)

`curl -fsSL https://raw.githubusercontent.com/platformio/platformio-core/develop/platformio/assets/system/99-platformio-udev.rules | sudo tee /etc/udev/rules.d/99-platformio-udev.rules`

You might need to reboot afterwards as manually reloading rules and triggering doesn't always work with `EasyInstall.py`

4. Clone the FZEasyMarauderFlash repo

`git clone https://github.com/SkeletonMan03/FZEasyMarauderFlash`

5. Change directory into the cloned repo

`cd FZEasyMarauderFlash`

6. Install required dependencies (With the override for ease of use. Doing this in a VM anyways.)

`pip install -r requirements.txt --break-system-packages`

7. Execute `EasyInstall.py`, which will download the binaries on first launch

`python ./EasyInstall.py`

You should be greeted with the following selection screen:

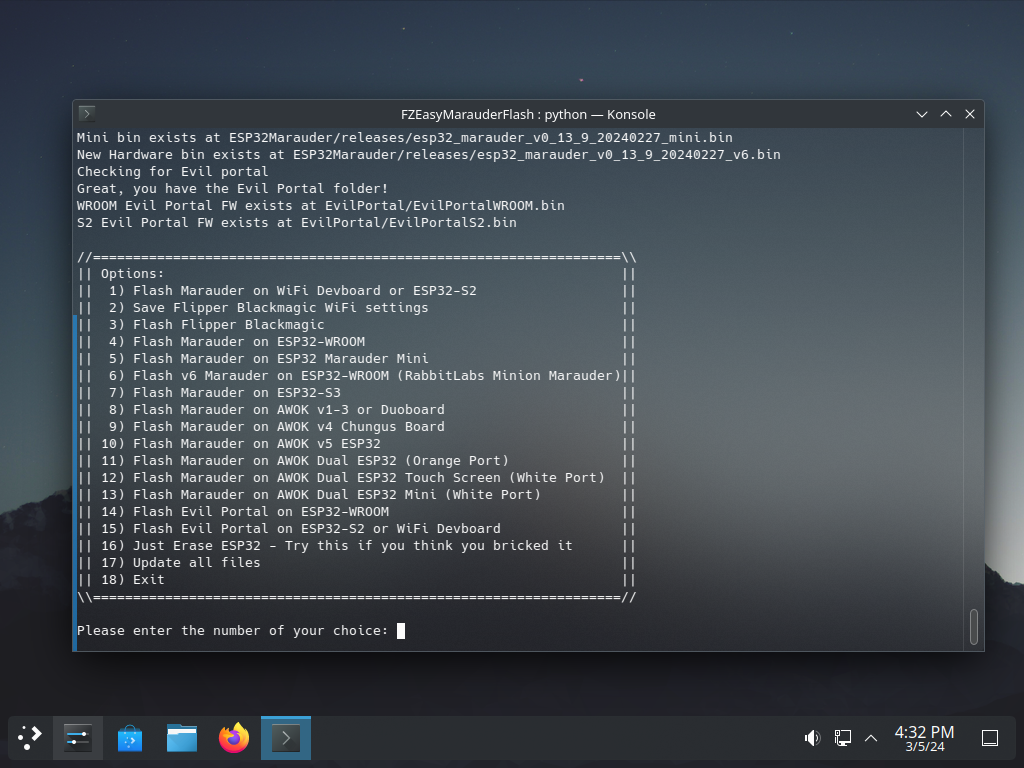
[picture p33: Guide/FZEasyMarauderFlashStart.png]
Easy Flash start screen


8. At this point, hold down the `BOOT` button on your ESP32 board and plug the board into your Computer using a USB-C cable

9. Select the firmware you wish to install. For Marauder, choose `1`, for Black magic, choose `3`, and for Evil Portal, choose `15`. In this example, we're gonna install Marauder with `1`

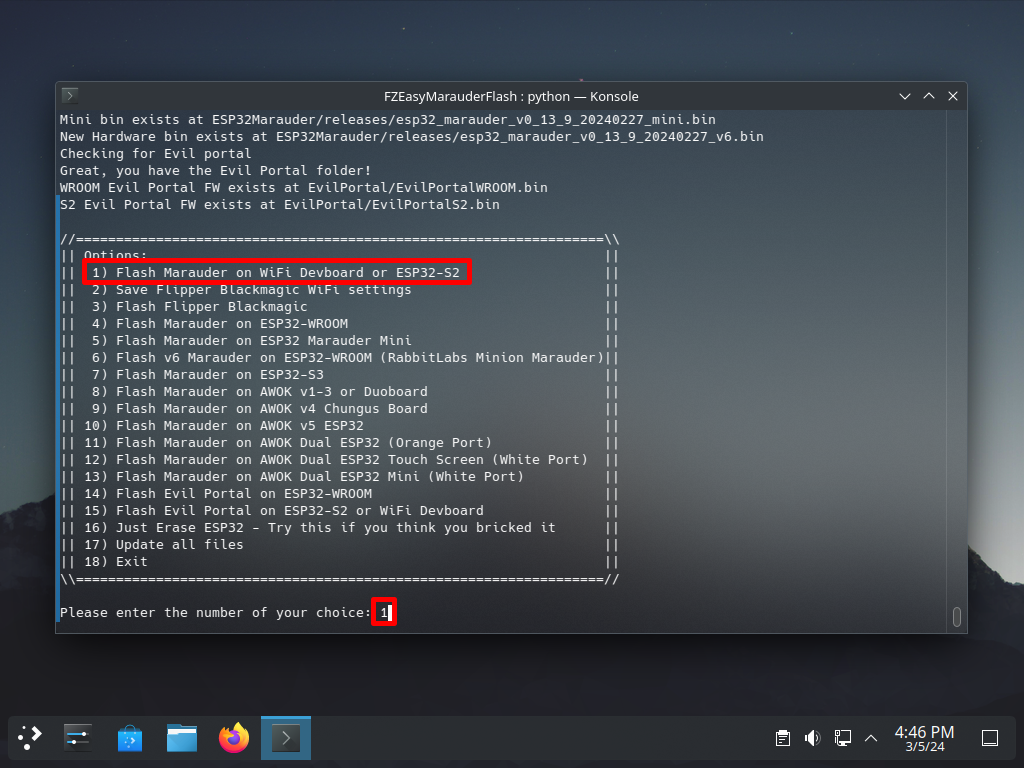
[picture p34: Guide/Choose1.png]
Choose1


10. This will take a few seconds. After the flash is complete you'll get the following confirmation:

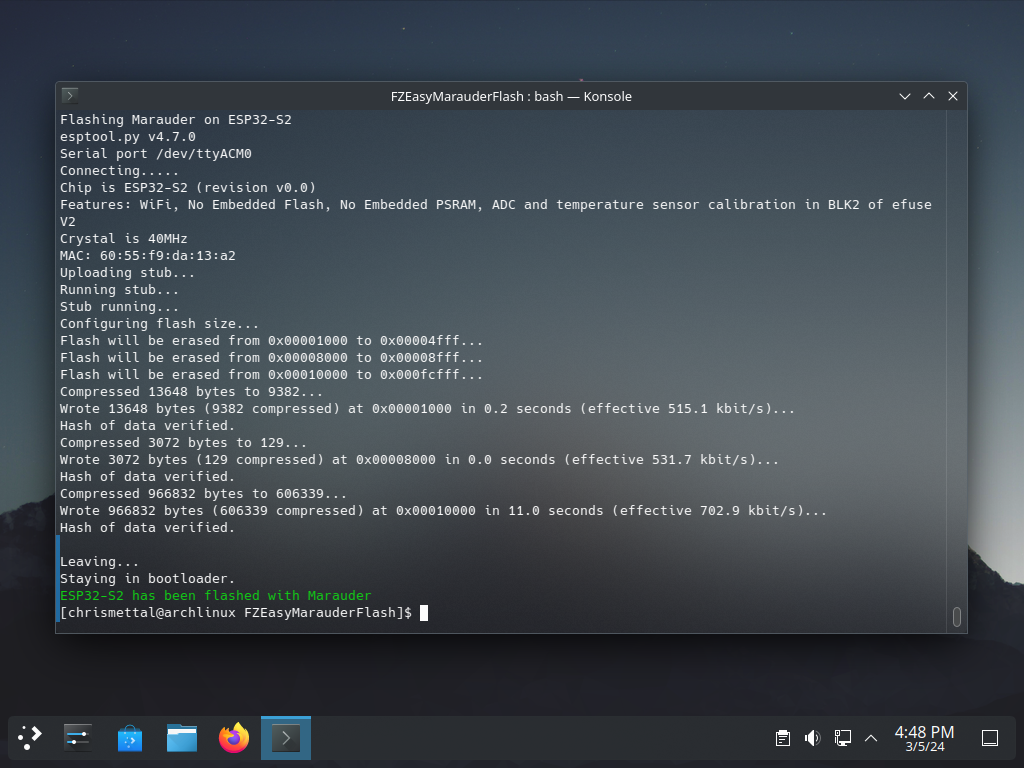
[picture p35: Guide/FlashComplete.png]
FlashComplete


11. Pressing the `RESET` button on the backpack at this point will make the board restart with the new firmware. Marauder will confirm successful installation by blinking the LED briefly in White, Yellow, Red, before shutting the LED off.

12. Inserting the board into your Flipper, you can test the functionality by opening the Wifi Marauder app (Present in Unleashed firmware or similar) and executing a simple AP scan

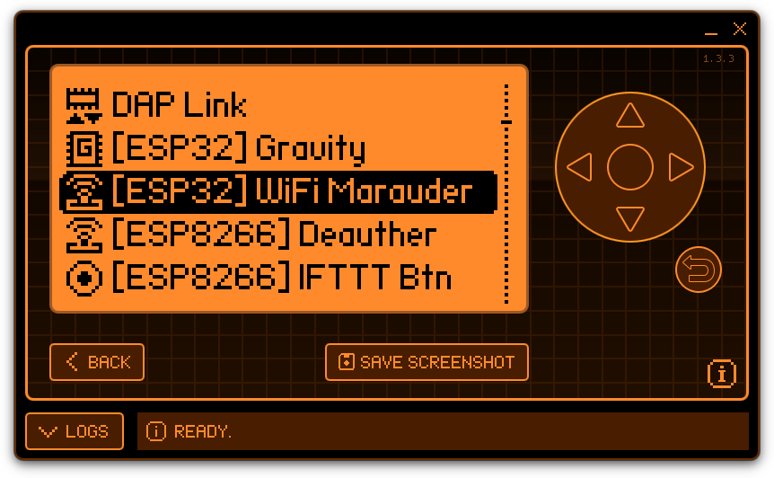
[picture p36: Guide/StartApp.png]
StartApp


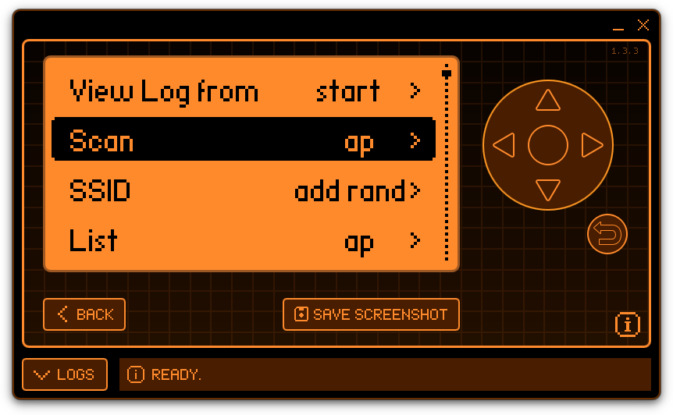
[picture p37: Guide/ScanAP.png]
ScanAP


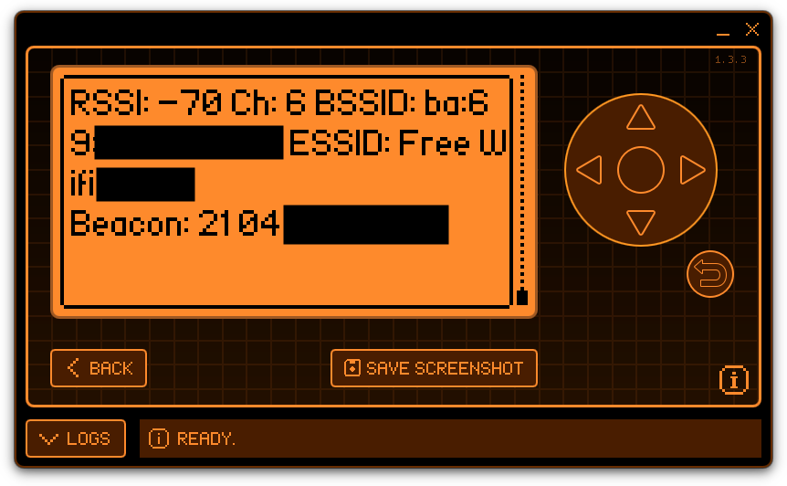
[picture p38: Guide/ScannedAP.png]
ScannedAP


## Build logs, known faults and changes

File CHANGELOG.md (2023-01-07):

 # Changelog
All notable changes to this project will be documented in this file.

The format is based on [Keep a Changelog](https://keepachangelog.com/),
and this project adheres to [Semantic Versioning](https://semver.org/spec/v2.0.0.html).

## [Unreleased]

## [0.0.1]

### Added
- nothing
  
### Changed
- nothing

### Deprecated
- nothing

### Removed
- nothing
  
### Fixed
- nothing
  
### Security
- nothing

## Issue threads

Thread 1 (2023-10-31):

No rubber case fit?

jtmkrueger, 2023-10-31:
Would you recommend changes to the pcbs if one wanted to use this without the rubber case on the flipper?

Chrismettal, 2023-10-31:
In my experience, way more people use a case on the Flipper than people running bare. As I didn't want to have multiple variants for all PCBs I opted to make all PCBs fit the Flippers case.

This is also influenced by the fact, that regular pin headers will naturally stand a bit proud of the top of the flipper.

This is what the boards look like if used on a Flipper without a case:

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

It would be possible to modify the backpack connector PCB to be 2mm shorter so the boards would snugly fit the back of the Flipper itself, rather than the rubber sleeve, but that would also mean updating all the 3D printable cases for both versions.

All in all, we are talking about 2mm here, it's not the end of the world to rock the Flipper sleeveless with these boards.

jtmkrueger, 2023-10-31:
> modify the backpack connector PCB

Maybe it'd just be easier to just modify the case to print a bit different? What do you think?

jtmkrueger, 2023-10-31:
Then I can order the PCB's from you and just do a different case print 😸

Chrismettal, 2023-10-31:
That is a nice idea, yeah. Giving the case 2mm longer walls towards the Flipper's back would make the stack more stable even if used without a case.
Can't say that it would look particularly great but it should be a good option for people not using the sleeve.. Let me see when I get the time to add case options for that. (Unless you want to take care of that yourself?)

jtmkrueger, 2023-10-31:
I can certainly try! I’ll let you know when my kit shows up (ordered one today)

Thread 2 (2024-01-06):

Does the raspberry pi zero 2 fit/work?

spitfire, 2024-01-06:
Does the raspberry pi zero 2 fit the backpack/work with pwnagotchi?

Chrismettal, 2024-01-07:
Mechanically the 2 should fit just fine, and since the UART is still in the same place, communication with the Flipper through this backpack will also work, so the backpacks itself have no reason not to work with Zero 2's.

However, I remember some talk within the Pwnagotchi project itself about the Zero 2 not being easily compatible, though some people seem to have managed it. Pwnagotchi is a different project entirely though so Pi compatibility would best be discussed over there.

I personally don't have access to a Zero 2 so I am unable to test on my side for now. If someone sent me a Zero 2 i'd love to confirm. Obiously if someone else tests this I'll update the description as well.

spitfire, 2024-01-07:
Thanks for the information, I was asking about the physical side, and I know I have to do my research on the Pwnagotchi side. I'll let you know if I learn anything

Closed 2024-01-07.

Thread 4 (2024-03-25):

Access to boot and reset buttons

briped, 2024-03-25:
A small suggestion for any future iterations of the case. Add holes/openings in the case. over the boot and reset buttons, so it's possible to press them without having to disassemble the board from the case.

I'm going to find a small drill and make some holes myself, but seeing as you've made a small hole to see the LED through, two more for the buttons would probably be simple for you to make (not me, I couldn't CAD if my life depended on it).

Thanks for a nice product :)

Chrismettal, 2024-03-26:
Good Idea. I guess we could integrate a button extension into the case without adding another part to the BOM.

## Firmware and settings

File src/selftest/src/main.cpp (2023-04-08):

//-----------------------------------------------------------------------------
//  ESP32 / SD backpack selftest
//-----------------------------------------------------------------------------
//
// Small program to test functionality of the ESP32 / SD backpack
// to be run without being plugged into a Flipper, but with a serial
// terminal being connected through the USB-C jack
//
// Stuff that could be tested (Not neccessarily all implemented yet):
// - Serial communication through the USB jack
// - Open up a Wifi AP
// - Fade through all LED colors
// - R/W to/from a plugged in SD card
// - Apply PullUps to LPUART lines and read if voltage is HIGH
// - Output /something/ to all remaining ESP GPIOs


//-----------------------------------------------------------------------------
//  Includes
//-----------------------------------------------------------------------------
// General
#include <Arduino.h>
#include "USB.h"
// SD Card
#include "FS.h"
#include "SD.h"
#include "SPI.h"
// Wifi
#include <WiFi.h>
#include <WiFiClient.h>
#include <WiFiAP.h>


//-----------------------------------------------------------------------------
//  Constants
//-----------------------------------------------------------------------------
// GPIOs
#define PIN_LED_R           6
#define PIN_LED_G           5
#define PIN_LED_B           4
#define PIN_I2C_PULLUP      3
#define PIN_LPUART_RX       17
#define PIN_LPUART_TX       18
// List of all GPIOs, HIGH for every GPIO that is going to be tested
#define NUMBER_GPIOS        43
const bool gpios[NUMBER_GPIOS] = {
  0,1,1,0,0,0,0,1,1,1,0,1,1,1,1,1,1,0,0,0,0,1,0,0,0,0,0,0,0,0,0,0,0,1,1,1,1,1,1,1,1,1,1
};

// Wifi
const char *SSID          = "SelftestAP";
const char *PASS          = "SelftestAP";
// General
#define MAX_PWM             255


//-----------------------------------------------------------------------------
//  Variables
//-----------------------------------------------------------------------------
bool singleResult;
bool overallResult;
unsigned long gpioStartTime;
USBCDC USBSerial;


//-----------------------------------------------------------------------------
//  Macros
//-----------------------------------------------------------------------------
#define SERIAL_DIVIDER USBSerial.println("----------------------------------------")


//-----------------------------------------------------------------------------
//  setup
//-----------------------------------------------------------------------------
void setup() {

  //---------------------------------------------------------------------------
  //  Serial
  //---------------------------------------------------------------------------

  USBSerial.enableReboot(HIGH);  
  USBSerial.begin(115200);
  USB.begin();

  // wait for serial connection
  //while (!USBSerial){;}
  USBSerial.println("Hoi!");
  delay(1000);


  SERIAL_DIVIDER;
  USBSerial.println("ESP32 backpack starting self test..");
  SERIAL_DIVIDER;

  delay(1000);

  //---------------------------------------------------------------------------
  //  GPIO setup
  //---------------------------------------------------------------------------
  // LEDs
  pinMode(PIN_LED_R, OUTPUT);
  pinMode(PIN_LED_B, OUTPUT);
  pinMode(PIN_LED_G, OUTPUT);
  analogWrite(PIN_LED_R, MAX_PWM);
  analogWrite(PIN_LED_G, MAX_PWM);
  analogWrite(PIN_LED_B, MAX_PWM);

  // I2C
  pinMode(PIN_I2C_PULLUP, OUTPUT);
  pinMode(PIN_LPUART_RX,  INPUT_PULLDOWN);
  pinMode(PIN_LPUART_TX,  INPUT_PULLDOWN);

  // GPIO test
  // Iterate through all pins
  for (int pin = 0; pin < NUMBER_GPIOS; pin++) {
    // Test only the ones enabled in the list
    if (gpios[pin]) {
      pinMode(pin, OUTPUT);
    }
  }


  //---------------------------------------------------------------------------
  //  Tests
  //---------------------------------------------------------------------------
  // Overall result memory
  overallResult = HIGH;

  //-----------------------------------
  // I2C
  //-----------------------------------
  // Test for low pullups
  SERIAL_DIVIDER;
  USBSerial.println("Starting I2C pin selftests");
  USBSerial.println("Disabling pullups");
  digitalWrite(PIN_I2C_PULLUP, HIGH);
  delay(50);

  singleResult = HIGH;

  if (digitalRead(PIN_LPUART_RX) == LOW) {
    USBSerial.println("OK  - GPIO_17 (LPUART_RX) low");
  } else {
    USBSerial.println("BAD - GPIO_17 (LPUART_RX) stuck high");
    singleResult = LOW;
  }

  if (digitalRead(PIN_LPUART_TX) == LOW) {
    USBSerial.println("OK  - GPIO_18 (LPUART_TX) low");
  } else {
    USBSerial.println("BAD - GPIO_18 (LPUART_TX) stuck high");
    singleResult = LOW;
  }

  // Test for high pullups
  USBSerial.println("Enabling pullups");
  digitalWrite(PIN_I2C_PULLUP, LOW);
  delay(50);

  if (digitalRead(PIN_LPUART_RX) == HIGH) {
    USBSerial.println("OK  - GPIO_17 (LPUART_RX) high");
  } else {
    USBSerial.println("BAD - GPIO_17 (LPUART_RX) stuck low");
    singleResult = LOW;
  }

  if (digitalRead(PIN_LPUART_TX) == HIGH) {
    USBSerial.println("OK  - GPIO_18 (LPUART_TX) high");
  } else {
    USBSerial.println("BAD - GPIO_18 (LPUART_TX) stuck low");
    singleResult = LOW;
  }

  // Print individual result
  SERIAL_DIVIDER;
  if (singleResult) {
    USBSerial.println("OK  - I2C Pullup tests OK!");
  } else {
    USBSerial.println("BAD - I2C Pullup tests failed!");
  }

  // Combine test results
  overallResult = overallResult && singleResult;

  
  //-----------------------------------
  // SD card
  //-----------------------------------
  /*
  singleResult = HIGH;
  SERIAL_DIVIDER;
  USBSerial.println("Starting SD card test");


  SPIClass spi = SPIClass(HSPI);
  spi.begin(36, 37, 35, 10);


  // Try mounting card
  if(!SD.begin(10, spi)){
    USBSerial.println("BAD - Card Mount Failed");
    singleResult = LOW;
  } else {
    uint8_t cardType = SD.cardType();

    // Find card type
    if(cardType == CARD_NONE){
        USBSerial.println("BAD - No SD card attached");
        singleResult = LOW;
    } else {

      USBSerial.print("SD Card Type: ");
      if(cardType == CARD_MMC){
          USBSerial.println("MMC");
      } else if(cardType == CARD_SD){
          USBSerial.println("SDSC");
      } else if(cardType == CARD_SDHC){
          USBSerial.println("SDHC");
      } else {
          USBSerial.println("UNKNOWN");
      }

      // Print SD size
      USBSerial.printf("Total space: %lluMB\n", SD.totalBytes() / (1024 * 1024));
      USBSerial.printf("Used space: %lluMB\n", SD.usedBytes() / (1024 * 1024));

      // Print individual result
      SERIAL_DIVIDER;
      USBSerial.println("OK  - SD card found and mounted");
    }
  }

  // Combine test results
  overallResult = overallResult && singleResult;
  */

  //-----------------------------------
  // Evaluation
  //-----------------------------------
  SERIAL_DIVIDER;
  SERIAL_DIVIDER;
  if (overallResult) {
    USBSerial.println("OK  - All automated tests passed!");
  } else {
    USBSerial.println("BAD - One or more automated tests failed!");
  }
  SERIAL_DIVIDER;
  SERIAL_DIVIDER;
  USBSerial.println("Starting manual tests");


  //-----------------------------------
  // Wifi
  //-----------------------------------
  SERIAL_DIVIDER;
  USBSerial.println("Creating Wifi access point");

  //Start AP
  if (!WiFi.softAP(SSID, PASS)) {
    USBSerial.println("BAD - Can't start Access point!");
  } else {
    IPAddress myIP = WiFi.softAPIP();
    USBSerial.print("OK  - AP created, IP: ");
    USBSerial.println(myIP);
    USBSerial.println("Please try connecting to AP 'SelftestAP' manually using the password 'SelftestAP'");
  }


  //-----------------------------------
  // LED
  //-----------------------------------
  SERIAL_DIVIDER;
  USBSerial.println("Starting LED test, please observe if LED shows R, G then B");

  // Blink all colors a few times
  for (int iteration = 1; iteration <= 3; iteration++) {
    // Red
    for (int value = MAX_PWM; value >= 0; value--) {
      analogWrite(PIN_LED_R, value);
      delay(1);
    }
    for (int value = 0; value <= MAX_PWM; value++) {
      analogWrite(PIN_LED_R, value);
      delay(1);
    }
    // Green
    for (int value = MAX_PWM; value >= 0; value--) {
      analogWrite(PIN_LED_G, value);
      delay(1);
    }
    for (int value = 0; value <= MAX_PWM; value++) {
      analogWrite(PIN_LED_G, value);
      delay(1);
    }
    // Blue
    for (int value = MAX_PWM; value >= 0; value--) {
      analogWrite(PIN_LED_B, value);
      delay(1);
    }
    for (int value = 0; value <= MAX_PWM; value++) {
      analogWrite(PIN_LED_B, value);
      delay(1);
    }

    delay(500);
  }

  SERIAL_DIVIDER;
  USBSerial.println("LED Test done.");


  //-----------------------------------
  // GPIO
  //-----------------------------------
  SERIAL_DIVIDER;
  USBSerial.println("Starting GPIO Test."); 
  USBSerial.println("Each remaining exposed GPIO will flash n times, where n is the GPIO number.");
  USBSerial.println("Each flash will be 1ms HIGH and 1ms LOW.");
  USBSerial.println("Every 100ms the next pin is started.");
  USBSerial.println("This test will repeat forever without further commandline instructions"); 
  SERIAL_DIVIDER;
}


//-----------------------------------------------------------------------------
//  loop
//-----------------------------------------------------------------------------
void loop() {

  //-----------------------------------
  // GPIO
  //-----------------------------------
  // Iterate through all pins
  for (int pin = 0; pin < NUMBER_GPIOS; pin++) {
    // Test only the ones enabled in the list
    if (gpios[pin]) {

      gpioStartTime = millis();

      // Blink for n cycles
      int cycle = 1;
      while (cycle <= pin) {
        digitalWrite(pin, HIGH);
        delay(1);
        digitalWrite(pin, LOW);
        delay(1);
        cycle++;
      }
      
      // wait for 100ms to be over
      delay(100 - (millis() - gpioStartTime));
      
    }
  }
  
  USBSerial.println("Starting back at GPIO_00.."); 
}

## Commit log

2023-01-07 [PCB] Start designing connecting PCB
    [Connecting-piece.kicad_pcb, Connecting-piece.kicad_sch]
2023-01-07 [PCB] Initial version of connector done
    [Connecting-piece.kicad_pcb]
2023-01-07 [PCB] Start creating ESP32 board
    [ESP32.kicad_pcb, ESP32.kicad_sch]
2023-01-07 [3D] Create project to visualize PCBs
    [flipper-zero-backpacks.FCStd]
2023-01-07 [PCB][Connector] Modify B2B to 2.5mm overlap
    [Connecting-piece.kicad_pcb]
2023-01-07 [PCB][3D][Connector][ESP32] Somewhat happy with initial mechanical design of PCB
    [Connecting-piece.kicad_pcb, ESP32.kicad_pcb, flipper-zero-backpacks.FCStd]
2023-01-07 [3D] Start creating shell
    [flipper-zero-backpacks.FCStd]
2023-01-07 [PCB][ESP32] Create PowerStage schematics
    [ESP32.kicad_sch]
2023-01-07 [PCB][ESP32] Continue schematic
    [ESP32.kicad_sch]
2023-01-08 [ESP32] Finish routing schematic
    [ESP32.kicad_sch]
2023-01-08 [ESP32] Assign footprints and LCSC numbers to all parts
    [ESP32.kicad_sch]
2023-01-09 [ESP32] Add SD card to schematic
    [ESP32.kicad_sch]
2023-01-09 [ESP32] Start PCB layout
    [ESP32.kicad_pcb, ESP32.kicad_sch]
2023-01-11 [ESP32] Start PCB routing over
    [ESP32.kicad_pcb]
2023-01-12 [ESP32] Continue routing PCB
    [ESP32.kicad_pcb]
2023-01-15 [ESP32] Finish copper routing
    [ESP32.kicad_pcb]
2023-01-15 [ESP32] Optimize routing
    [ESP32.kicad_pcb]
2023-01-15 [ESP32] GND via stitching
    [ESP32.kicad_pcb]
2023-01-15 [ESP32] Fix DRC violations
    [ESP32.kicad_pcb]
2023-01-15 [ESP32] Place silk designators, clearing all DRC warnings
    [ESP32.kicad_pcb]
2023-01-15 [ESP32] Add silk doc / logos
    [ESP32.kicad_pcb]
2023-01-15 [ESP32] Add JLCPCB tooling holes
    [ESP32.kicad_pcb]
2023-01-15 [ESP32] Remove stray silk string
    [ESP32.kicad_pcb]
2023-01-15 [ESP32] Import "finished" PCB into FreeCAD
2023-01-15 [ESP32][Connector] Add JLC order number
    [Connecting-piece.kicad_pcb, ESP32.kicad_pcb]
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2023-01-16 [ESP32] Export production files and order PCBs
    [ESP32.kicad_pcb, ESP32.kicad_sch, ESP32_Bom.csv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]
2023-03-30 [ESP32][Connector] Update to KiCad 7
    [Connecting-piece.kicad_pcb, Connecting-piece.kicad_sch, ESP32.kicad_pcb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]
2023-04-01 [ESP32] Remove R1
    [ESP32.kicad_pcb, ESP32.kicad_sch]
2023-04-01 [ESP32] Add partial self-test firmware
2023-04-02 [ESP32] Minor rewire
    [ESP32.kicad_pcb]
2023-04-02 [ESP32] Enable selftest USB Serial and fix LED test
    [main.cpp]
2023-04-08 [ESP32][Selftest] Add GPIO test; Disable SD test; Optimize LED test
2023-04-08 [ESP32][Selftest] Update pinmodes for GPIO to be tested
2023-04-08 [ESP32][Selftest] temporarily enable GPIO testing SD card pins
2023-04-08 [ESP32][Selftest] Invert pullup enabler because of P-Channel FETs
    [main.cpp]
2023-04-08 [ESP32][Selftest] Enable pulldowns on LPUART selftest
2023-04-09 [ESP32] Fix RX/TX swapped
    [ESP32.kicad_pcb, ESP32.kicad_sch]
2023-04-09 [ESP32] Utilize space gained by removing R1
    [ESP32.kicad_pcb]
2023-04-09 [ESP32] Fix LED footprint
    [ESP32.kicad_pcb, ESP32.kicad_sch]
2023-04-09 [ESP32] Run DRC
    [ESP32.kicad_pcb]
2023-04-09 [ESP32] Fix a bit of silkscreen clipping
    [ESP32.kicad_pcb]
2023-04-09 [Doc] Document ESP32 antenna jumper
2023-04-09 [3D] Update ESP32 case; Add case with antenna
2023-05-01 [ESP32] Generate 2 BOMs for internal vs external antenna
    [ESP32_Bom_ExternalAntenna.csv, ESP32_Bom_InternalAntenna.csv]
2023-05-01 [Clean] Add empty - clean project
    [Clean.kicad_pcb, Clean.kicad_sch]
2023-05-01 [Proto] Add simple protoboard variant
    [Protoboard.kicad_pcb, Protoboard.kicad_sch]
2023-05-01 [3D] Export printable cases for Protoboard and ESP32 with internal antenna
    [ESP32_Bare.3mf, ESP32_Bare.step, ESP32_InternalAntenna.3mf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]
2023-05-01 [3D] Rename bare case
    [Bare.3mf, Bare.step]
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2023-05-13 [Doc] Update ESP32 info
2023-05-13 [Doc] Add guide for ordering your own boards
2023-06-26 [RPI] Add Rasperry Pi Zero adapter variant
    [Raspberry.kicad_pcb, Raspberry.kicad_sch]
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2023-06-30 [RPI] Draw schematic
    [Raspberry.kicad_pcb, Raspberry.kicad_sch]
2023-06-30 [RPI] Route PCB
    [Raspberry.kicad_pcb, Raspberry.kicad_sch]
2023-06-30 [RPI] Export fabrication files
    [Raspberry.kicad_pcb, Raspberry_Bom.csv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]
2023-08-15 [ESP32] Add Documentation and 3D files for external antenna variant
    [ESP32_ExternalAntenna.3mf, ESP32_ExternalAntenna.step]
2023-08-15 [RPI] Fix PCB not actually connected to Flipper
    - Added previously removed headers that act as mandatory vias from one side to the other.
    [Raspberry.kicad_pcb, Raspberry.kicad_sch]
2023-08-15 [RPI] Order boards
    [Raspberry.kicad_pcb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]
2023-08-16 [RPI] Add 3D printed case for the RPI board
    [Raspberry.3mf, Raspberry.step]
2023-09-17 [RPI] Fix HDMI jack not fitting in the case perfectly
    [Raspberry.3mf, Raspberry.step]
2023-12-04 [RPI] Add some more room for screws in case
    [Raspberry.3mf, Raspberry.step]
2024-03-05 Fix case links
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2024-04-27 Remove JLCJLCJLCJLC String from all PCBs
    [Connecting-piece.kicad_pcb, ESP32.kicad_pcb, Raspberry.kicad_pcb]
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2024-07-31 Improve Pi backpack case:
    - Remove 0.5mm of material at the overhang at the top to give Filament space to droop down
    - Remove all bridges from lower segment so Pi can be inserted easier
    - Enlarge FPC space by 2mm either direction
2024-07-31 [RPI]Update case exports
    [Raspberry.3mf, Raspberry.step]
2024-12-14 [3D] Apply 0.5mm enlargement fix to all cases
2024-12-14 [3D] Export all 4 cases with 0.5mm fix
    [Bare.3mf, Bare.step, ESP32_ExternalAntenna.3mf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]
2025-11-01 [PCB] Put ESP32-S2-MINI-2 into schematic and board to check for viability
    [ESP32.kicad_pcb, ESP32.kicad_sch]
2025-11-29 Do an exact pin compare and find an error in USB D+ D-
    [ESP32.kicad_sch, WroverToMini.ods]
2025-11-29 Reroute with ESP32-MINI
    [ESP32.kicad_pcb]
2025-11-29 Run through DRC
    [ESP32.kicad_pcb]
2025-11-29 Update Silk Date
    [ESP32.kicad_pcb]
2025-11-29 [ESP32] Order PCBs
    [ESP32.kicad_pcb, ESP32_Bom_ExternalAntenna.csv, ESP32_Bom_InternalAntenna.csv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]

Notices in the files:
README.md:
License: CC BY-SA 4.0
